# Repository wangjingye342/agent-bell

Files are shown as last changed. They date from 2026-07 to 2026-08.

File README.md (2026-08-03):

# AgentBell

独立的桌面小工具项目：电脑上 **Claude Code / Codex** 完成一轮对话时，局域网里的 ESP32-C3 设备
**蜂鸣 + 震动**，并在 OLED 上显示「哪台电脑 / 哪个智能体 / 哪个对话」完成了。
还带一个**带登录的网页控制台**，手机/电脑可随时开关蜂鸣/震动/勿扰。

> 本项目独立于气象站「仿真器」(aurora-weather-station)，自成一个文件夹与 git 仓库，互不影响。

```
   电脑（可多台）                          局域网                 AgentBell 设备
 ┌──────────────────┐   POST /notify   ┌──────────────────────────────────┐
 │ Claude  Stop hook │ ───────────────▶ │ ESP32-C3（HTTP 服务器 + mDNS）    │
 │ Codex   notify    │                  │  → 蜂鸣 + 震动 + OLED 显示        │
 │ tools/agent-bell/ │                  │  + 网页控制台 agent-bell.local    │
 └──────────────────┘                  └──────────────────────────────────┘
```

## 目录

| 路径 | 内容 |
|---|---|
| `agent_bell/` | **设备固件**（ESP32-C3 + SSD1306 OLED）+ Wokwi 预览。见 [agent_bell/README.md](agent_bell/README.md) |
| `agent_bell/WIRING.md` | **接线表**（先看这个） |
| `tools/agent-bell-bridge/` | **推荐：电脑侧桥接程序**（托盘常驻，免 hook 自动转发系统通知 + 自动发现设备 + 远程设置）。见 [tools/agent-bell-bridge/README.md](tools/agent-bell-bridge/README.md) |
| `tools/agent-bell/` | 电脑侧 hook 方案（Claude/Codex 适配器，备用）。见 [tools/agent-bell/README.md](tools/agent-bell/README.md) |
| `tools/ino-sim/` | 从气象站项目拷来的**屏幕模拟器**（备用，见下） |

## 快速开始

1. 接线：照 [agent_bell/WIRING.md](agent_bell/WIRING.md)（⚠ OLED / 触摸必须 3V3）。
2. 填 WiFi + 改网页登录密码：编辑 [agent_bell/agent_bell.ino](agent_bell/agent_bell.ino) 顶部配置区。
3. 编译烧录（在本项目根目录下）：
   ```sh
   arduino-cli compile --fqbn esp32:esp32:esp32c3:PartitionScheme=huge_app --output-dir agent_bell/build agent_bell
   arduino-cli upload -p COM5 --fqbn esp32:esp32:esp32c3 --input-dir agent_bell/build agent_bell
   ```
4. 打开 `http://agent-bell.local/` 登录 → 点「发一条测试通知」自测。
5. 接电脑（二选一）：
   - **推荐**：装桥接程序（免 hook，Claude/Codex 发系统通知即自动转发），见 [tools/agent-bell-bridge/README.md](tools/agent-bell-bridge/README.md)。
   - 备用：hook 方案（Claude 的 Stop hook / Codex 的 notify），见 [tools/agent-bell/README.md](tools/agent-bell/README.md)。

## 关于 ino-sim 模拟器

`tools/ino-sim/` 是从气象站项目搬来的屏幕模拟器（把 Arduino 屏幕输出渲染成 PNG，让 AI 能"看到"UI 效果）。

**注意**：它目前只支持 Adafruit_GFX / ST7735（RGB565 彩屏），**还不能渲染本项目的 SSD1306 单色 OLED（U8g2 驱动）**。
所以本项目的界面预览暂时走 **Wokwi**（SSD1306 是 Wokwi 原生器件，见 [agent_bell/README.md](agent_bell/README.md)）或真机。
若以后想让 ino-sim 也能预览这块 OLED，需要给它加一个 SSD1306/U8g2 单色后端——可作为后续任务。

## 状态

- ✅ 已完成：WiFi 通知（蜂鸣 + 震动 + 中文屏显）、网页控制台（登录 + 开关蜂鸣/震动/勿扰 + 测试，设置存 flash）、
  电脑侧通知器 + 两个适配器（已本地端到端测过）、两版固件编译通过。
- ⏳ 待真机验证：接线上电、WiFi 连接、控制台、真跑一轮对话自动触发。
- 🔒 以后：长按录音 → 语音识别 → 回填输入框 → 双击确认发送（触摸手势、麦克风引脚 7/20/21 已预留）。

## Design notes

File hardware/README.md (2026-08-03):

# AgentBell 单板 PCB — 前期设计资料

把 AgentBell 从"面包板+杜邦线"集成到**一块嘉立创可打样+贴片**的板子。

> **当前状态：可行性/需求确认阶段，还不是可直接生产的设计源。**
> 先阅读 [FEASIBILITY_REVIEW.md](FEASIBILITY_REVIEW.md)，并填写
> [MEASUREMENTS_NEEDED.md](MEASUREMENTS_NEEDED.md)。`SCHEMATIC.md` 和 `BOM.csv` 是前期草案，
> 在实物尺寸、电源方案和最终料号确认前不能直接用于下单。

> 这份是人可读的前期方案，不是可直接上传 JLC 的 Gerber/CPL。实际原理图、布线、ERC/DRC、
> Gerber、BOM 和 CPL 仍需在 EDA 工具中完成和复核。

新增资料：

- [SUPERMINI_CARRIER_SPEC.md](SUPERMINI_CARRIER_SPEC.md)：SuperMini 尺寸、引脚、供电和手焊封装；
- [PCBA_STRATEGY.md](PCBA_STRATEGY.md)：除 SuperMini 外全部由嘉立创贴装的生产策略。
- [EDA_AUTOMATION_PLAN.md](EDA_AUTOMATION_PLAN.md)：嘉立创 EDA API 自动绘制、检查和生产文件导出方案。
- [POWER_PATH.md](POWER_PATH.md)：USB 优先、边充边用、自动电池切换和关机充电架构。
- [COMPACT_DESIGN.md](COMPACT_DESIGN.md)：主板尺寸目标、双面叠放和小型器件选择约束。

## 方案总览

- **主控**：ESP32-C3 SuperMini 使用自定义 2×8 混合封装平放手焊；这是唯一手焊电子器件。天线端
  **悬出板边或在其下方/前方完整禁铜**。
- **屏**：0.96" SSD1306 OLED（单独一块），主板出 **4P 排线座**（3V3/GND/SDA/SCL）引到外壳正面。
- **全 SMD 由 JLC 贴**：小型无源蜂鸣器、薄型 EC05 编码器、独立小型确认键、SMD 振动马达，
  以及全部驱动/阻容/触摸/电源器件。
- **触摸**：不用触摸模块——在 PCB 顶层做一块**铜箔触摸片**接 TTP223（周围挖空地铜、盖阻焊、丝印画图标）。
- **供电基线**：主板 USB-C + BQ24074 power-path + 单节锂电池 + 电源开关。插 USB 时 USB 优先
  供系统并同时充电；拔 USB 自动切换电池；关机仍能充电。
- **手工焊/装配**：只手焊 SuperMini；OLED、电池和旋钮帽采用插接/压装，其余电子器件由 JLC 贴好。

## 供电架构

```
主板 USB-C ──► BQ24074 power-path ──► 电池
                    │
                    └─► VSYS ──► 电源开关/后级升压 ──► 5V_SYS
                                                     ├─► SuperMini 5V
                                                     └─► 外设 3.3V
```
- 主板 USB-C 负责日常供电和充电；SuperMini 自带 USB-C 只作烧录服务口。
- 插 USB 时系统负载优先，余量用于充电；拔 USB 自动由电池供电。
- 电源开关关闭后系统负载断电，但充电管理仍工作。
- SuperMini 的 3.3V 输出与载板 3.3V 不相连，避免两个稳压器并联。
- 使用 SuperMini USB 烧录前必须把主电源关闭，并通过 PCB 防倒灌器件进一步隔离。

## 引脚分配（沿用现固件，避开 strapping 2/8/9）

| GPIO | 功能 |
|---|---|
| 1  | 编码器 CLK (A) |
| 3  | 蜂鸣器（经 SS8550 低有效驱动）|
| 4  | 触摸（TTP223 输出）|
| 5  | OLED SDA |
| 6  | OLED SCL |
| 7  | 编码器 DT (B) |
| 10 | 振动马达（经 SS8050 高有效驱动）|
| 20 | 编码器按键 SW |
| 3V3/GND | 供电 |
| 空闲 | 0, 21（可留调试焊盘）|

## 平面布局（小型双面叠放）

```
主板正面：USB-C / 充电电源 / 小型编码器 / 按键 / 触摸 / 蜂鸣器 / 马达 / 接口
主板背面：ESP32-C3 SuperMini 手焊，元件面朝外

目标板框：优先尝试约 24×32mm；若热设计、USB、天线或机械件无法满足，则控制在 28×38mm 内。
```
- SuperMini 与正面 SMT 器件在平面上重叠，利用双面面积；天线区域例外，所有层完整 keepout。
- 编码器、按键、触摸片和 USB-C 放在外壳可操作边；蜂鸣器声孔和马达受力面保持无遮挡。

## 嘉立创下单要点

1. 在立创EDA 画原理图（按 `SCHEMATIC.md` 连接表）→ 导入元件（按 `BOM.csv` 的 LCSC 编号）→ PCB 布局布线 → DRC。
2. 下单：PCB + SMT 贴片；小型版包含 QFN、电源器件、薄型编码器、蜂鸣器和马达。是否适用
   Economic PCBA、双面装配或治具，以最终 BOM 在下单页面的实时提示为准。
3. **不贴、留给你手工**：仅 SuperMini；它在 BOM/CPL 中标为 DNP。OLED、电池使用工厂已贴好的
   SMD 防呆连接器和预制线束。
4. 收板后：检查电源 → 手焊 SuperMini → 插接屏幕/电池 → 烧录固件。

详见 [SCHEMATIC.md](SCHEMATIC.md)（逐块原理图+连接表）与 [BOM.csv](BOM.csv)（元件+LCSC 编号）。

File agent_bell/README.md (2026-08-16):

# AgentBell 设备固件

ESP32-C3 + OLED + 蜂鸣器 + 震动 + 旋转编码器做的桌面小工具：
**电脑上 Claude Code / Codex 完成一轮对话 → 它蜂鸣 + 震动 + OLED 显示「哪台电脑 / 哪个智能体 / 哪个对话」。**

> 这是独立于 `weather_station` 气象站的新子项目，两者互不影响。

```
   电脑（可多台）                          局域网                 AgentBell 设备
 ┌──────────────────┐   POST /notify   ┌──────────────────────────────────┐
 │ Claude  Stop hook │ ───────────────▶ │ ESP32-C3 (HTTP 服务器 + mDNS)     │
 │ Codex   notify    │  computer/agent/ │  → 蜂鸣 + 震动 + OLED 显示        │
 │ tools/agent-bell/ │  conversation/…  │  agent-bell.local                 │
 └──────────────────┘                  └──────────────────────────────────┘
```

## 文件

| 路径 | 作用 |
|---|---|
| `agent_bell.ino` | 设备固件（WiFi + HTTP 服务器 + U8g2 中文 OLED + 蜂鸣/震动/编码器菜单）|
| `WIRING.md` | **接线表**（先看这个）|
| `secrets.example.h` | WiFi 凭据模板（复制为 `secrets.h` 填入，已 gitignore）|
| `diagram.json` / `wokwi.toml` | Wokwi 界面预览（可选，用 SIM_DEMO 版固件）|
| `../tools/agent-bell-bridge/` | **推荐：电脑侧桥接程序**（托盘常驻，自动转发系统通知 + 远程设置）（[说明](../tools/agent-bell-bridge/README.md)）|
| `../tools/agent-bell/` | 电脑侧 hook 方案 + Claude/Codex 适配器（备用）（[说明](../tools/agent-bell/README.md)）|

## 硬件

见 [WIRING.md](WIRING.md)：OLED(GPIO5/6)、旋转编码器(GPIO1/7/20)、蜂鸣器(GPIO3)、震动(GPIO10)。
⚠ OLED 和编码器必须 3V3 供电（C3 不耐 5V）。

## 构建 & 烧录

```sh
# 装库（一次）
arduino-cli lib install U8g2
# 编译（huge_app 分区容纳中文字库）
arduino-cli compile --fqbn esp32:esp32:esp32c3:PartitionScheme=huge_app \
    --output-dir agent_bell/build agent_bell
# 烧录（换成你的串口，如 COM5）
arduino-cli upload -p COM5 --fqbn esp32:esp32:esp32c3 --input-dir agent_bell/build agent_bell
```
> 本机 arduino-cli 用绝对路径 `/c/Program\ Files/Arduino\ CLI/arduino-cli.exe`；PATH 坑见项目记忆。
> 已验证：正式版占 3MB 分区的 40%（1.27MB），内存宽松。

## 首次使用

1. 复制 `secrets.example.h` 为 `secrets.h`，填入你的 WiFi（`secrets.h` 已 gitignore，不会上传）。
2. 按上面命令编译、烧录。
3. 上电后设备连 WiFi，待机屏出现（IP 可在旋钮菜单「设备状态」里看）。
4. 自测链路：转一下旋钮进菜单，选「模拟通知」→ 应蜂鸣 + 震动 + 屏显。
   从电脑发也行：浏览器访问 `http://agent-bell.local/api/test`，或命令行
   `python ../tools/agent-bell/notify.py --demo`。
5. 接上智能体（二选一）：
   - **推荐**：装[桥接程序](../tools/agent-bell-bridge/README.md)（托盘常驻，Claude/Codex 一发系统通知就自动转发，免 hook）。
   - 备用：hook 方案见[电脑侧说明](../tools/agent-bell/README.md)（Claude 的 Stop hook、Codex 的 notify）。
     本仓库已内置项目级 `.claude/settings.json`，**在本项目里结束一轮对话即会触发**（设备在线时）。

## 待机屏（左右半屏模块）

待机时屏幕分**左右两个 64×64 半屏**，各自从同一个模块池里任选，共 8 种：

**宇航员**（星空 + 自转太空人）· **数字时钟** · **模拟表盘** · **竖排大钟** · **日历** · **信息面板**（未读/WiFi/IP/开机时长）· **雷达扫描** · **流星夜空**

改法三选一（同一份设置，存 flash 掉电不丢）：

- 设备旋钮菜单「**左屏样式 / 右屏样式**」——选择器背景就是实时渲染的待机屏，转一格换一种，所见即所得；
- 桥接程序**设置窗口**的设备设置区；
- `POST /api/settings` 的 `lsty` / `rsty` 字段（0–7，顺序同上）。

时钟类模块的时间来自 SNTP（`ntp.aliyun.com`，UTC+8），联网后自动同步；未同步时显示 `--:--` 或占位表姿。

## 设置怎么调

分两类：

- **编译期**（改完要重新编译烧录）：`agent_bell.ino` 顶部配置区——引脚（OLED/蜂鸣器/震动/编码器）、
  `MDNS_NAME`、`OLED_ADDR`、震动极性 `VIB_ACTIVE_HIGH`、编码器每档沿数 `ENC_RAW_PER_DETENT`、
  提示音音序表 `MELODIES` / 震动节奏 `ALERT_VIB`。WiFi 凭据在 `secrets.h`（见上）。
- **运行期**（改完即生效，存 flash 掉电不丢，无需重烧）：
  - **设备旋钮菜单**（转=选，短按=进/确认，长按=返回），按使用频率分组排序：
    勿扰（短按即切，行内显示开/关）→ 通知组（提示音·停留自动试听、通知音量、通知震动）→
    反馈组（反馈方式、反馈音量、反馈震动——「反馈」指转/按旋钮时的提示，与通知独立）→
    待机屏（左/右屏样式）→ 旋钮（方向·短按即翻转、灵敏度）→ 省电组（自动熄屏、自动关机）
    → 立即熄屏、立即关机（深睡 µA 级，**转动**旋钮开机；按键不在 C3 唤醒脚
    范围内）、WiFi 状态（短按立刻重连）、重新配网 → 模拟通知、设备状态；
  - **桥接程序设置窗口**（设备在线时出现设备设置区）；
  - **HTTP API**：`POST /api/settings`（字段见下）。

## 电源与省电（电池供电必读）

v2 板的电池路径是 `VBAT → SS34 → SuperMini 板载 LDO → 3.3V`，余量只有零点几伏。
WiFi 发射峰值电流（19.5dBm 约 350mA）会把 3.3V 轨拽到欠压阈值以下 → 芯片复位 →
重启又连 WiFi → 又复位，表现为**屏幕定格 + 蜂鸣器连续响**（每次开机的初始化响一下）。

固件侧的应对：**只有一档「省电但够用」，没有模式可选**（板上既没有 USB 检测脚也没有
电池 ADC，固件无法自知供电来源，所以一律按电池的约束跑）：

| 项 | 取值 | 为什么 |
|---|---|---|
| 发射功率 | 按 RSSI 自适应 11 / 13 / 15 / 17dBm | 弱信号时不吝啬——TCP 重传比多发几个 dBm 更费电，也更容易撞穿电脑侧超时 |
| WiFi 休眠 | 调制解调器休眠（随 DTIM 醒来收包）| 省下的 ~60mA 连续电流是续航的大头；代价约 +0.1s 延迟，对提醒设备无感 |
| 主频 | 80MHz | 实测 HTTP 处理只占 p50 19ms，降频不影响响应 |
| 通知音量 | 封顶 70% | **防掉电，不是省电**：蜂鸣 ~200mA + 马达 ~100mA 会和 WiFi 收包峰值叠在刚收到通知那一刻 |

> 早期有「自动/性能/省电」三档，其中「自动」会在掉过一次电后**永久**锁死省电模式
> （NVS 粘性标记只写不清，插 USB 也回不去）。既然电池小、目标就是省电，现在直接
> 合并成一档，那个 bug 也随之消失。

配套措施：开机用缓存的 BSSID + 信道直连（跳过全信道扫描，缩短高电流窗口）；
掉电复位后先显示「电池电压不足」并等 2.5s（连续掉电 6s）让电芯回压再连网；
`esp_reset_reason()` 的掉电次数在菜单「设备状态」和 `/api/info` 的 `brownouts` 里可查
（正常供电恒为 0）。

> 根治要靠硬件：5V 节点加 220~470µF 缓冲电容、把 SS34 换成理想二极管省掉 0.4V 压降，
> 或按 `hardware/POWER_PATH.md` 的原方案加升压。

## HTTP 端点

所有端点均无需登录（仅限局域网用，HTTP 明文传输，别把设备暴露到公网）：

| 端点 | 作用 |
|---|---|
| `GET /` | **网页设置控制台**：全部设置读写 + 试听/试震 + 待看通知（手机/电脑输设备 IP 即用）|
| `GET /api/notes` | **待看**通知 JSON 数组（不是历史存档：设备上按一下旋钮即整批清空）|
| `GET\|POST /notify` | 收通知（`computer/agent/conversation/message`，表单编码；给 hook / 桥接程序用）|
| `GET /healthz` | 探活 |
| `GET /api/info` | 设备身份 JSON（`app:"agent-bell"`、mac、ip、rssi、uptime_s、brownouts 掉电次数、lowpower 是否已转省电；桥接程序扫描网段时靠它确认）|
| `GET /api/settings` | 读全部运行时设置（JSON，含 `melodies`/`panes` 名称表）|
| `UDP 47317` | 局域网发现应答：收到 `AGENTBELL?` 就把 `/api/info` 的 JSON 回给发送方。一个广播包替掉 254 次 TCP 扫描——那种扫描的突发会把设备自己打趴（实测漏检率 5%→20%），而 UDP 走 lwIP 自己的任务，不经 WebServer 的串行路径 |
| `GET /api/state` | `{info, settings, notes}` 一次拿完——设备一次只服务一个 HTTP 请求，多台电脑连时把 3 次请求合成 1 次是最实在的省 |
| `POST /api/settings` | 改设置，字段全部可选、只改传了的：开关 `buzz/vib/dnd/encrev/nwake`（0\|1）、强度 `bvol/vvol/fbvol/fbvib`（0–100）、`tone`（提示音 0–6）、`fb`（反馈方式 0–3）、`encdet`（灵敏度 1–3）、`lsty/rsty`（半屏样式 0–7）、`aoff`（自动熄屏分钟 0/1/2/5/10/20/30）、`apwr`（自动关机分钟 0/10/20/30/60/120/240）；另有动作参数 `play=1` 试听 / `vibtest=1` 试震。应答同 GET |
| `GET\|POST /api/test` | 注入一条固定测试通知，完整走响铃+震动+屏显，验证链路 |

## 操作（编码器）

**转** = 移动/调整，**短按** = 进入/确认，**长按 ≈0.5s** = 返回/回待机。详见 [WIRING.md](WIRING.md)。
（触摸模块已移除：其"返回"功能与编码器长按完全重合，且 PCB 放不下；GPIO4 空出留给以后的麦克风。）

## 界面预览（可选，不用真机）

两条路都行：

- **ino-sim（推荐，快）**：`tools/ino-sim` 已支持 U8g2 单色屏，一条命令把各个界面
  （待机各模块组合 / 通知 / 勿扰…）逐屏截成 PNG（场景脚本见
  [tools/ino-sim/scenarios/agent_bell.scn](../tools/ino-sim/scenarios/agent_bell.scn)，可注入 `lsty`/`rsty` 预览任意半屏组合）：
  ```sh
  python tools/ino-sim/simulate.py agent_bell/agent_bell.ino \
      --scenario tools/ino-sim/scenarios/agent_bell.scn --out tools/ino-sim/out_ab
  ```
- **Wokwi（交互式）**：用 `diagram.json` + `wokwi.toml`（VSCode 里 F1 → Wokwi: Start Simulator），
  指向 **SIM_DEMO 版**固件（开机自注入示例通知、跳过联网）：
  ```sh
  arduino-cli compile --fqbn esp32:esp32:esp32c3:PartitionScheme=huge_app \
      --build-property "compiler.cpp.extra_flags=-DSIM_DEMO" \
      --output-dir agent_bell/build-sim agent_bell
  ```

## 状态 / 下一步

- ✅ 已完成：WiFi 通知（蜂鸣 + 震动 + 中文屏显）、旋钮丝滑菜单（全部设置存 flash）、
  待机屏左右半屏模块（8 种可选 + 实时预览选择器）、网页设置控制台 + `/api/*` 桥接接口、
  电脑侧桥接程序 + hook 方案两条链路（已本地端到端测过）、ino-sim U8g2 界面预览。
- ⏳ 待真机验证：接线上电、WiFi 连接、`/api/test` 三件套、真跑一轮对话自动触发。
- 🔒 以后：长按录音 → 发电脑 → 微信输入法语音识别 → 回填输入框 → 双击确认发送（GPIO4 已空出留给麦克风）。

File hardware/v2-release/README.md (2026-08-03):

# AgentBell v2 载板 — 交付包（2026-07-28）

本目录是本轮 EasyEDA 设计（Claude + easyeda-agent 全程自动化 + 人工确认）的**最终交付物**。
EasyEDA 工程：AgentBell / Board3（Schematic3 + PCB3）。

## 文件清单

| 文件 | 用途 |
|---|---|
| `AgentBell-Gerber.zip` | **制造文件**，直接上传嘉立创下单（2 层 / 1.6mm / 过孔盖油，其余默认） |
| `AgentBell-BOM.csv` / `.xlsx` | **物料表**（带立创 C 号；CSV 为 UTF-16 Tab 分隔，Excel 打开无碍） |
| `s0-design-spec.json` | 设计档案：决策记录 / 引脚表 / BOM / 器件官方手册审计结论（s0-final-8） |
| `golden-netlist.json` | 金标准网表（22 网络，原理图与 PCB 双向对账基准） |
| `worklog/` | 过程工作文件（求解器脚本、中间 dump、审查材料），可整目录删除 |

## 板子速览

- **48 × 24mm**，左上 R10 圆角，双面 2 层
- 编码器轴心 = 圆弧圆心 **(10, 14)**；SuperMini 贴背面，USB 朝下悬出 2.4mm，天线朝上入全层禁布窗
- 锂电充电：TP4054 @ **147mA**（R8=6.8k，换 2k≈500mA）+ SS34 电源自动切换 + B+/B− 焊线孔
- 定位柱：Ø3.0 孔 ×3，孔心 (4,3.5) / (44.5,3.5) / (44.5,20.5)，间距 40.5 / 17.0 / 43.9mm
- 焊线孔全部丝印标注；阻容值全部丝印标注

## 已知无害项（下单可忽略）

1. DRC 剩 1 处 VBAT 同网重叠（铜皮合并，零风险）
2. 背面器件**位号**文字未镜像（平台 API 限制）；**阻容值标注是实物正向的**，焊接以它为准
3. 板厂 DFM 的丝印压盘/锐角提示为顾问级，正常生产

## 首次上电顺序

1. 不接电池，USB 直插 SuperMini → 整机应正常
2. 断 USB 接电池 → 电池带机
3. 电池 + USB 同插 → CHG 灯亮=充电中，充满自灭

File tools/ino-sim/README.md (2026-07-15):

# ino-sim — Arduino ST77xx / TFT screen simulator

Render an Arduino `.ino` sketch's TFT screen output to **PNG images + an HTML
gallery on your Mac**, so you (and the AI) can see exactly what the UI code draws
without flashing hardware.

Built for the ESP32-C3 + ST7735s (128×160) workflow, but works for any sketch
that draws through **Adafruit_GFX / Adafruit_ST7735 / Adafruit_ST7789** or
**TFT_eSPI**.

## How it works (why it's pixel-faithful)

The sketch is compiled on the host against thin Arduino shims, but its drawing is
redirected into an in-memory framebuffer using the **real Adafruit_GFX rendering
code** (vendored in `third_party/`). Because GFX draws *everything* — text,
lines, circles, the manual pixel arcs — through the same `drawPixel` path the
hardware uses, and `GFXcanvas16` applies the exact rotation transform the panel
applies via MADCTL, the rendered image matches the physical screen.

Both libraries share one engine: `GFXcanvas_fb` (extends the real
`GFXcanvas16`). `Adafruit_ST7735/ST7789` is a thin subclass; `TFT_eSPI` is an
API facade forwarding to the same engine — so common primitives render
identically across both.

```
.ino ──▶ simulate.py ──▶ clang++  (sketch + shims + real Adafruit_GFX + runtime)
                              │
                          framebuffer  ──▶ out/<frame>.png  +  out/index.html
                              ▲
                       scenario.scn  (sensor / time / touch inputs)
```

## Requirements

- macOS/Linux with `clang++` (or `g++`) and **zlib** (preinstalled on macOS).
- `python3`.

No Arduino toolchain or internet needed at run time. The canonical Adafruit_GFX
source is vendored under `third_party/Adafruit_GFX/` (BSD-licensed) for offline,
reproducible builds.

## Usage

```sh
# Capture all three pages of the demo sketch (uses scenarios/default.scn):
python3 tools/ino-sim/simulate.py sketch_jun18a/sketch_jun18a.ino

# Custom scenario, output dir, and upscale factor:
python3 tools/ino-sim/simulate.py path/to/sketch.ino \
    --scenario tools/ino-sim/scenarios/default.scn \
    --out tools/ino-sim/out --scale 4
```

Options:

| flag | default | meaning |
|---|---|---|
| `--scenario FILE` | `scenarios/default.scn` | scenario script to run |
| `--backend auto\|adafruit\|tft_espi` | `auto` | force a backend (auto-detected from `#include`s) |
| `--scale N` | `4` | integer nearest-neighbor upscale for the PNGs |
| `--out DIR` | `<tool>/out` | output directory |
| `--keep` | off | keep the generated `build/sketch.cpp` for debugging |

Outputs land in `out/`:
- `out/<name>.png` — one image per `snap`, upscaled `--scale`×. **Read these to
  see the UI.**
- `out/index.html` — a dark-themed gallery of all frames; open in a browser.

## Scenario DSL

A scenario is a plain-text script, one command per line; `#` starts a comment.
It sets inputs, advances simulated time while calling `loop()`, and snapshots the
screen. This lets you reach **any** UI state.

```
title My UI preview        # heading shown in index.html

touchpin 1                 # which GPIO the tap/hold commands drive (demo: 1)
temp 26.5                  # DHT.readTemperature() returns this (°C)
hum 60                     # DHT.readHumidity() returns this (%)
time 14:30:00              # NTP/getLocalTime clock; or "2026-06-19 14:30:00"
pin 3 high                 # set any input pin level (high/low/1/0)
analog 2 512               # set an analogRead() value

run 500ms                  # run loop() for 500 ms of simulated time
tap                        # short press touchpin (advance a page, etc.)
hold 1500ms                # long press (e.g. demo toggles the backlight)
snap climate               # capture the screen as out/climate.png
rotation 1                 # (rarely needed) force a rotation
```

Durations accept `us`, `ms`, `s`, or a bare number (= milliseconds). Time
advances **only** inside `run`/`tap`/`hold`, so `millis()`-based debounce and
refresh logic behave exactly as on hardware.

## Supported API

**Arduino core**: `Serial` (→ stderr), `millis/micros/delay`, `pinMode/
digitalRead/digitalWrite/analogRead`, `random`, `String`, `F()`/PROGMEM, math
macros, `Print::printf`.

**Libraries shimmed**: `Adafruit_GFX`, `Adafruit_ST7735`, `Adafruit_ST7789`,
`TFT_eSPI` (common drawing + text subset), `DHT`, `WiFi`, `time.h`
(`configTime`/`getLocalTime`).

**Not yet supported**: TFT_eSPI sprites (`TFT_eSprite`), smooth/anti-aliased &
custom-loaded fonts, true SPI timing. Sketches using those will fail to compile
or fall back to the GLCD font. The classic GLCD 5×7 font is fully supported and
matches hardware.

## Layout

```
simulate.py            orchestrator (ino→cpp, prototype-gen, compile, run)
scenarios/             scenario scripts (default.scn captures the 3 demo pages)
examples/              sample sketches (e.g. tft_espi_demo)
src/arduino_shim/      Arduino.h, Print, String, pgmspace, WiFi, DHT, time
src/gfx_backend/       GFXcanvas_fb engine + Adafruit_ST7735/ST7789 + colors
src/tft_espi_backend/  TFT_eSPI.h facade
src/runtime/           framebuffer PNG export, scenario parser, main, html viewer
third_party/Adafruit_GFX/  vendored canonical GFX (BSD)
build/ out/            generated (gitignored)
```

## Adding a sketch

Just point `simulate.py` at it. The orchestrator prepends `#include <Arduino.h>`
and auto-generates function prototypes (mirroring the Arduino IDE), and picks the
backend from the sketch's includes. Write a scenario that drives it to the states
you want to preview, then read the PNGs.

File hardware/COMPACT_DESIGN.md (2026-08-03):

# AgentBell 小型化设计约束

更新日期：2026-07-18

## 设计目标

在保持以下全部功能的前提下尽量减小主板和整机体积：

- ESP32-C3 SuperMini；
- USB 优先、锂电边充边用、拔线自动切电池；
- 电源开关，关机仍可充电；
- OLED 外接；
- 触摸按键；
- 旋转输入及确认/返回按键；
- 无源蜂鸣器；
- 振动马达。

小型化优先级：

1. 不能牺牲电气安全、天线性能和可制造性；
2. 优先减小 PCB 长宽；
3. 再控制整机厚度；
4. 仍需保留可操作的 USB、旋钮/转轮、按键和触摸区域；
5. 不为了几平方毫米使用难以采购或无法返修的非标准器件。

## 尺寸基准和目标

SuperMini 本体约 `18.0 × 22.5 mm`，因此它决定了主板的最小核心面积。

当前目标分两档：

| 目标 | 板框建议 | 说明 |
|---|---|---|
| 激进目标 | 约 24 × 32 mm | 需要双面高密度布局、超小编码器/按键，接口位置受限 |
| 稳妥目标 | 不超过 28 × 38 mm | 仍然很小，电源热设计、USB、声孔和连接器更容易安排 |

最终板框以元件真实 courtyard、天线 keepout、USB 插头空间和外壳操作面为准。不会为了满足一个预设
数字而违反 DRC 或挤压散热铜皮。

电池和 OLED 不计入主板板框，但通常会决定整机最终长宽和厚度。

## 双面叠放策略

- 嘉立创贴装器件集中在主板正面；
- SuperMini 作为唯一手焊件放在主板背面，元件面朝外；
- 主板正面器件可以与 SuperMini 在 XY 方向重叠，以节省平面面积；
- SuperMini 对应区域避免顶层过孔残桩和高出焊点；
- 天线端的上下两面和所有铜层做完整 keepout，且不放电池和线缆；
- BQ24074 的散热焊盘、USB 输入电容和功率地回路优先于极限压缩；
- 升压芯片、电感和输入/输出电容紧凑成一组，不跨板走大电流回路；
- 蜂鸣器声孔、马达受力面和触摸电极不能被 SuperMini 或电池遮挡。

## 小型器件基线

| 功能 | 原候选 | 小型化候选 | 大致外形/封装 | 结论 |
|---|---|---|---|---|
| 充电和 power-path | TP4056 草案 | BQ24074RGTR / C54313 | QFN 3×3 mm | 锁定候选 |
| 5V 升压 | 未定 | TPS61023DRLR / C919459 | SOT-563 1.6×1.2 mm | 优先候选 |
| 编码器 | EC11J1525402 / C209762 | EC05E1220401 / C116648 | 约 7.6×6.2×2.7 mm | 待机械确认 |
| 编码器按键 | EC11 内置 | EVQ-P7K01P / C5736840 | 约 3.5×2.9 mm | EC05 无按压时使用 |
| 蜂鸣器 | MLT-8530 / C94599 | MLT-5020 / C94598 | 约 5.2×5.2×2.5 mm | 小体积优先 |
| 触摸 | 淘宝模块 | TTP223 小封装 + PCB 电极 | IC 小封装 | 锁定方向 |
| 电池连接器 | PH2.0 | 1.0/1.25mm 卧贴防呆座 | 2P/3P | 等电池线束确认 |
| OLED 连接器 | PH2.0 4P | 1.0mm 卧贴 4P | 4P | 等屏幕线束确认 |
| 阻容 | 0402 | 0402 | 1.0×0.5 mm | 保持，兼顾密度和返修 |

## 旋转输入的取舍

原来的 EC11 约 15 × 18 mm，且高度超过 20 mm，是主板小型化的最大障碍，正式小型版不再使用。

EC05 是 5mm 中空轴的薄型编码器，适合做侧边拨轮/小转盘，但预计不包含 EC11 那样的按压开关。
因此保留两个输入：

- EC05：旋转菜单；
- 独立小型贴片轻触键：确认/短按/长按返回。

固件可继续使用原 `ENC_SW` GPIO20，电气功能不变，只是物理按键从旋钮轴下移到旁边。

如果最终必须坚持“旋钮本身可按压”，主板需要改用更大的 EC11 类器件，PCB 长宽或厚度必然增加。

## 蜂鸣器和马达

MLT-5020 相比 MLT-8530 面积明显更小，但声压约 75dB，低于原候选的 80dB；正式板会保留 MOSFET
驱动和匹配其 4kHz 特性的音调设置。若真机感觉不够响，可升级到稍大的 MLT-5030（约 80dB），
无需改变整体架构。

振动马达的尺寸直接影响体感。8mm 马达搜索到的候选是引线/通孔类型，不符合“只有 SuperMini
手焊”的要求；因此优先寻找嘉立创可 SMT 的最小扁平马达。若最小可自动贴装马达需要治具，需在
下单成本和体积之间取舍。

## PCB 工艺约束

- 默认 4 层板有利于在小面积内保持连续地平面、电源完整性和天线隔离；若成本优先再评估 2 层；
- 0402 阻容；不主动使用 0201；
- 功率线、USB 输入、充电和马达回路不按普通信号线最小线宽处理；
- QFN 散热焊盘需要合理钢网开窗和接地过孔；
- USB-C 固定脚、编码器/按钮受力区不能因为缩板而削弱铜皮和板边距离；
- 板框确定后输出 1:1 PDF，与 SuperMini、USB 插头、电池和 OLED 实物叠放检查。

## 外壳和整机体积

主板做到很小后，电池往往成为最大器件。电池容量越大，整机厚度/面积越大。最终应选择扁平 LiPo
贴在主板远离天线的一侧，并通过绝缘片隔离。电池不得覆盖 ESP32 天线，也不得压在蜂鸣器声孔或
触摸电极背面。

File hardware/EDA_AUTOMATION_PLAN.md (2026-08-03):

# 嘉立创 EDA 自动绘制与生产文件方案

更新日期：2026-07-18

## 结论

本机具备直接生成嘉立创 EDA 专业版工程和生产文件的可行工具链。推荐使用嘉立创/EasyEDA 的
官方 API skill 与 API Gateway，而不是仅靠鼠标自动化绘制。

已确认环境：

- 嘉立创 EDA 专业版 `V3.2.166` 已安装并正在运行；
- 本机安装包含 `pro-api 0.3.4` 接口定义；
- 已安装 Codex skill：`C:\Users\wjy\.codex\skills\easyeda-api`；
- skill 提供原理图、PCB、封装、工程管理、DRC 和制造数据导出 API；
- 当前尚未检测到 EasyEDA Bridge 服务，EDA API Gateway 扩展仍需安装/启用。

## 推荐工作流

```text
确定电源与机械要求
    ↓
API 查询嘉立创器件库、锁定 LCSC 料号和真实封装
    ↓
创建嘉立创 EDA 原理图
    ↓
ERC / 电源与驱动复核
    ↓
创建 PCB、板框、SuperMini 自定义封装和天线 keepout
    ↓
器件布局、布线、铺铜
    ↓
DRC + 3D/机械检查 + BOM/库存检查
    ↓
导出生产包
```

## 可以生成的交付物

最终 `hardware/production/` 计划包含：

- 嘉立创 EDA 专业版工程备份文件（`.epro`/`.epro2`）；
- 原理图 PDF；
- Gerber ZIP；
- 钻孔文件（包含在 Gerber 包内并单独复核）；
- BOM（CSV/XLSX，含 LCSC 料号）；
- Pick and Place / CPL 坐标文件；
- PCB 3D STEP 文件；
- 装配图和关键极性说明；
- DRC/ERC 检查记录；
- `ORDER_README.md`，列明嘉立创下单选项、DNP 器件和后焊 SuperMini 方法。

Gerber 可用于多数 PCB 厂打裸板；Gerber + BOM + CPL 用于嘉立创 PCBA。嘉立创 EDA 原生工程便于
在下单前继续人工检查和修改。

## 仍然不能跳过的检查

“能自动生成”不等于“未经检查就安全下单”。最终下单前至少要确认：

1. 电池容量、是否自带保护板、连接器型号和极性；
2. 外壳/板框尺寸、安装孔和编码器位置；
3. SuperMini 实物与 1:1 自定义封装重合；
4. OLED 实际线序、连接器和线长；
5. 蜂鸣器声孔、马达治具和编码器高度；
6. 嘉立创下单页面上的库存、贴装方向、扩展料和治具费用；
7. ERC/DRC 无未解释错误；
8. Gerber、BOM、CPL 在下单预览器中再次核对。

## 锂电版本的电源原则

用户已经确认需要 USB 优先、边充边用和自动电池切换。正式架构见
[POWER_PATH.md](POWER_PATH.md)，主充电/电源路径芯片暂定 `BQ24074RGTR / C54313`。

正式方案会加入：

- 单节锂电池连接器；
- 充电管理；
- 电池保护（若电池本身不带保护）；
- 电源开关；
- 明确的 USB/电池电源路径；
- 3.3V 稳压和负载瞬态储能；
- 电池电压检测（建议）；
- 防反接/过流保护和测试点。

不再使用旧草案的 `TP4056 + LDO`。BQ24074 负责充电和 power-path；电源开关控制后级系统电源，
关机时仍能充电。SuperMini 的烧录 USB 与主板日常充电 USB 分开，并增加防倒灌和丝印警告。

## 工具接入前置步骤

1. 在嘉立创 EDA 专业版安装并启用 `run-api-gateway.eext`；
2. 启动本机 EasyEDA Bridge 服务；
3. 验证 Bridge 健康状态和唯一 EDA 窗口连接；
4. 先执行只读 API：读取当前工程、文档和器件库；
5. 新建独立工程 `AgentBell-PCB`，不覆盖当前空白/测试工程；
6. 分阶段保存快照，原理图确认后再开始 PCB。

EDA 扩展安装完成后，可以从 API 自动建工程开始推进。

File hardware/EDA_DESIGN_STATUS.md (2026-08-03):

# AgentBell 嘉立创 EDA 设计状态

更新时间：2026-07-18

## 当前工程

- 工程：`AgentBell`
- Board：`Board1`
- 原理图：`Schematic1 / P1`
- PCB：`PCB1`
- PCB 文档 UUID：`043746d370790ae8`
- Bridge：已连接，后台 API 操作正常

`pcb_Document.importChanges()` 在当前嘉立创 EDA/Bridge 版本中会后台执行，未必显示“应用变更”窗口。因此，是否同步成功必须通过器件、UniqueId 和焊盘网络审计判断，不能以是否弹窗为准。

## 已完成

- 保留并整理了 55 个功能器件。
- 补入并关联了 `U1 BQ24074RGTR`，原理图/PCB UniqueId 为 `gge1`。
- 重建原理图的网络端口和短导线，消除了相邻引脚坐标重叠造成的意外短接。
- 修正了充电、升压、LDO、I2C 上拉和状态灯等错误网络。
- 逐器件比较原理图与 PCB：位号、UniqueId、全部焊盘网络为 0 处差异。
- PCB 已完成首轮紧凑布局。
- 当前板框约 `36.0 mm x 46.0 mm`。
- PCB 已切换为 4 层：Top / Inner1 / Inner2 / Bottom。
- ESP32-C3 SuperMini 放在 Bottom 层，其余主要 SMT 器件放在 Top 层。
- 当前工程已保存，并在 `hardware/backup` 中保存了多个可回退版本。

## 尚未完成

- PCB 铜线尚未完成。
- GND 平面、接地过孔、SuperMini 天线完整禁布区尚未最终建立。
- 当前 DRC 仍会报告未布线连接错误。
- 仍有少量器件间距和封装内部槽孔检查项需要处理。
- 尚未生成可用于下单的 Gerber、BOM、CPL 和装配图。

## 自动布线接口情况

当前环境的 `pcb_Document.autoRouting()` 会在 0 ms 内返回全部网络失败，即使：

- 原理图与 PCB 逐焊盘网络一致；
- U1 的 UniqueId 已修复；
- PCB 已切换为 4 层；
- 飞线计算能够正常启动。

因此不能依赖该接口完成布线。后续应采用 API 手工分网布线，或在嘉立创 EDA 中使用前端布线功能。

## 投板限制

当前版本绝对不能直接投板。至少还需要：

1. 完成全部铜线和 GND 平面；
2. 建立 ESP32-C3 天线区域上下层禁铜、禁过孔、禁器件；
3. 复核 BQ24074 与 TPS61023 的高电流回路和散热；
4. DRC 中未布线错误归零，并处理真实间距错误；
5. 确认电池容量、允许充电电流、保护板、连接器极性；
6. 导出并复核 Gerber、BOM、CPL 和装配图。

## 当前关键风险

- 电池规格仍未确认，现有 `R1=1.78k` 对应的充电电流不应在未知电池上直接使用。
- SuperMini 自带 USB 与主板 5V 供电之间必须遵守防倒灌/烧录时断主电源要求。
- 贴片马达、蜂鸣器、编码器和连接器仍需结合实际外壳确认机械方向。

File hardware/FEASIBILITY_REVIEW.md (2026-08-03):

# AgentBell 集成 PCB 可行性评审（2026-07-18）

## 结论

这些功能可以集成到同一块主 PCB：

- ESP32-C3 SuperMini 主控子板
- 无源蜂鸣器及驱动
- 振动马达及驱动、续流保护
- 电容触摸按键
- 带按压的旋转编码器
- OLED 屏幕外接接口
- 电源输入、滤波、测试点和调试接口

屏幕继续做独立板很合理。第一版建议把主板定位为 **SuperMini 载板**，而不是立即把
ESP32-C3 芯片、Flash、晶振、USB 电路全部重画一遍。这样既能沿用现有固件，又能显著降低 RF、
USB 下载和焊接风险。

用户已确认装配目标：**除 ESP32-C3 SuperMini 手焊外，其余主板器件尽量全部由嘉立创贴装。**
现有候选蜂鸣器、编码器和振动马达均有嘉立创 SMT 条目；其中振动马达需要装配治具。详细安排见
[PCBA_STRATEGY.md](PCBA_STRATEGY.md)。

目前目录内的 `SCHEMATIC.md`、`BOM.csv` 是前期方案，不应直接用于下单。打板前还需要完成：

1. 确认所有实物的机械尺寸和引脚顺序；
2. 决定 USB 常供电还是锂电供电；
3. 确认 SuperMini 能否平贴焊接；
4. 用最终选定的立创商城料号核对封装、库存和贴装属性；
5. 画出真实 EDA 原理图/PCB，完成 ERC、DRC、Gerber 和坐标文件检查。

当前暂定首版为 USB 常供电，以便先完成明确且低风险的载板设计。如果用户确认必须加入锂电，正式
原理图将切换到带充电、保护和电源路径的版本。

## 从代码确认的接口

固件 `agent_bell/agent_bell.ino` 当前使用：

| 功能 | GPIO | 电气方向/说明 |
|---|---:|---|
| 编码器 A | 1 | 输入，上拉，双边沿中断 |
| 蜂鸣器 | 3 | PWM/音调输出；当前固件按“低有效 PNP 驱动”编写 |
| 触摸 | 4 | 数字输入；固件会在启动时学习空闲电平 |
| OLED SDA | 5 | I2C，3.3V |
| OLED SCL | 6 | I2C，3.3V |
| 编码器 B | 7 | 输入，上拉，双边沿中断 |
| 振动马达 | 10 | 20kHz PWM，高有效 |
| 编码器按键 | 20 | 输入，上拉，按下接地 |

代码避开了 GPIO2、GPIO8、GPIO9，并保留 GPIO0、GPIO21。PCB 上应把 0、21、3V3、GND、EN
做成测试焊盘，便于首板调试。

## 推荐的首版架构

### 方案 A：USB 常供电载板（推荐首板）

使用 SuperMini 自带 USB-C 负责供电和烧录：

```text
SuperMini USB-C
  ├─ 板载稳压器：只负责 SuperMini 自身 3.3V
  └─ 5V/VBUS 焊盘 → 载板 3.3V 稳压器 → OLED/触摸/编码器/蜂鸣器/马达
                                      └→ 蜂鸣器、马达各自经过驱动
```

优点：电路少、没有双 USB 口、没有充电和电源路径问题，最适合验证布局、交互和驱动电路。

新增资料已经确认 SuperMini 引出了 5V/VBUS、GND 和 3.3V。载板默认从 5V/VBUS 取 USB 电源并
自行稳压，不把两个 3.3V 稳压器输出并联。开发板资料明确要求外部供电和 USB 不能同时使用；详见
[SUPERMINI_CARRIER_SPEC.md](SUPERMINI_CARRIER_SPEC.md)。

### 方案 B：锂电版（第二版或确认需求后再做）

锂电版需要同时考虑电芯保护、充电电流、边充边用的电源路径和低电压关断。当前草案的
“TP4056 + LDO 直接带载”可以工作于某些场景，但不适合在参数未确认时直接出板：

- TP4056 本身不是完整的负载共享/电源路径管理；
- 1.2kΩ PROG 约对应 1A 充电，未必适合小电池；
- 电池电压下降后，普通 3.3V LDO 会逐渐失去稳压余量；
- 电池保护取决于电芯是否自带保护板；
- SuperMini 自带 USB 和主板充电 USB 同时插入时必须避免电源互相顶住。

如果确实需要电池，建议单独确定续航、充电口数量、电池容量和是否要求边充边用，再选择带
power-path 的充电方案或做明确的电源隔离。

## 各模块怎样集成

### 1. ESP32-C3 SuperMini

新增资料确认该版本约 18.00 × 22.50 mm、2×8 焊盘、两排基准间距 15.24 mm。首版做
**混合兼容手焊封装**：通孔用于定位/加固，外侧加长焊盘用于模块平放后的烙铁接触。模块覆盖区不
放元件，天线端伸出主板或做完整禁铜区。正式投板前仍需用 1:1 封装打印图与手头实物叠放核对。

### 2. 无源蜂鸣器

用户提供的 PDF 显示模块由无源蜂鸣器、9012 类 PNP 三极管和基极电阻组成，是低有效高边驱动。
PDF 上电阻标注为 22Ω；不建议未经实测就原样复制，尤其不应把该模块直接以 5V 供电并由 3.3V
GPIO 驱动。

推荐主 PCB 使用裸无源蜂鸣器 + 独立驱动：

- 首选逻辑电平 N-MOSFET 低边驱动，蜂鸣器电源可通过焊接跳线选择 3.3V/5V；
- GPIO 只驱动 MOSFET 栅极，不承担蜂鸣器电流；
- 采用低边驱动后，需要把固件蜂鸣器极性改为高有效；
- 若坚持完全不改固件，可保留 3.3V PNP 高边方案，但不要提供未经电平转换的 5V 档。

如果要拆现有模块上的蜂鸣器复用，必须测量蜂鸣器本体尺寸、脚距，并确认它确实是无源型号。

### 3. 振动马达

马达不能直接接 GPIO。推荐使用逻辑电平 N-MOSFET 低边驱动，并在马达两端放续流二极管。马达
附近增加 0.1µF 抑制电容，负载电源入口增加储能电容，电机大电流回路不要穿过 ESP32/OLED 的
地回路。

淘宝模块整板通常不能作为标准 SMT 料自动贴装。可选择：

- 主 PCB 做马达驱动，保留 2P 焊盘/连接器，复用现有马达；
- 选立创可贴的 SMD 币式马达，但必须用其官方封装并确认装配限制；
- 首板由你手工焊马达，风险最低。

### 4. 触摸开关

最适合集成：不再安装淘宝触摸模块，而是把 TTP223 类触摸 IC、去耦电容和触摸铜箔直接画在
主 PCB 上。触摸电极周围及其正下方要按触摸设计留出净空，并预留灵敏度电容焊盘。

如果触摸区域隔着较厚外壳，需先确定外壳材料和厚度；这会直接影响铜箔面积和灵敏度。

### 5. 旋转编码器

小型版不再使用 HW-040/大 EC11。当前优先候选为 `EC05E1220401 / C116648`，约
7.6×6.2×2.7mm，由嘉立创贴装。它使用中空轴转轮，若不带按压，则增加
`EVQ-P7K01P / C5736840` 小型贴片按键接原 GPIO20，固件功能保持不变。机械结构仍需在外壳阶段
确认拨轮直径、手指接触空间和按键位置。

### 6. OLED

屏幕分板保留。主板提供 4P 防呆连接器，并把引脚顺序同时印在丝印上：`3V3/GND/SDA/SCL`。
连接器型号和屏幕端线序必须最终确认；不能只写“JST 4P”，因为 PH、SH、XH 的间距完全不同。

## 嘉立创下单时哪些可以直接贴

“可以直接有”并不只取决于它是不是 SMD，还取决于下单当日的库存、封装、贴装面、器件高度和
装配规则。因此最终以立创 EDA/JLCPCB 下单页的 BOM 匹配结果为准。

| 类别 | 建议 | 原因 |
|---|---|---|
| 0402/0603/0805 阻容、LED | 工厂贴 | 标准 SMT，最适合自动贴装 |
| MOSFET/三极管、二极管、TTP223、电源 IC | 工厂贴 | 有明确 LCSC 料号和封装即可 |
| USB-C、常见 SMD JST 座、滑动开关 | 可工厂贴 | 需锁定精确料号、开口方向和机械孔 |
| SMD 蜂鸣器 | 工厂贴 | 小型版候选 C94598，约5.2mm，必须配独立驱动 |
| SMD 薄型编码器 | 工厂贴 | 小型版候选 C116648；独立确认键 C5736840 |
| 币式振动马达 | 工厂贴 | C22359894 当前候选支持 SMT，但需要装配治具 |
| ESP32-C3 SuperMini 整板 | 手焊 | 淘宝开发板不是标准 LCSC SMT 物料；平贴还依赖实物边缘焊盘 |
| 淘宝触摸/蜂鸣器/马达/HW-040 模块整板 | 手焊或取消模块 | 模块通常没有标准 PCBA 贴装料号和机器可识别包装 |
| OLED 模块、旋钮帽、锂电池、外接线 | 后装/手工装配 | 属外部模块或机械装配件 |

用户自己提供的散件并不等于经济型 PCBA 会自动帮忙贴。若要让工厂使用客供料，通常需要走
客供料/特殊装配流程并增加沟通和成本；对 5～10 块首板，自己焊关键机械件更合适。

## 打板前必须补齐的实物信息

请按 `MEASUREMENTS_NEEDED.md` 测量或拍照。尤其需要：

1. SuperMini 正反面高清照片，旁边放尺子；
2. SuperMini 两排孔的中心距、纵向脚距、板厚、底面最高元件高度；
3. 蜂鸣器模块正反面和丝印，蜂鸣器本体直径/高度/脚距；
4. 马达模块正反面、马达额定电压和启动/运行电流；
5. 触摸模块芯片丝印、输出空闲电平；
6. 编码器模块和裸编码器的轴高、轴型、安装孔尺寸；
7. OLED 接口间距、实际线序和连接方式；
8. 供电选择：长期 USB，还是必须电池；若用电池，提供容量和是否带保护板。

淘宝商品页在本次检查时跳转到了登录页，无法可靠读取 SKU 和尺寸，所以不能拿商品标题或其他
卖家的相似图片代替实物测量。

## 首版 PCB 的建议边界

首版目标应是“电气可靠、接口正确、能装进预期外壳”，而不是一次把所有特殊器件都交给工厂贴：

- JLC 贴：阻容、MOSFET、二极管、触摸 IC、连接器、蜂鸣器、编码器、振动马达；
- 你手焊：仅 SuperMini；OLED、电池等使用插接线束后装；
- PCB 同时给蜂鸣器和马达留替代封装/2P 接口，避免某一个淘宝器件尺寸不合导致整板报废；
- 所有外接接口旁标注电压、信号名和 1 脚；
- 预留 0Ω/焊接跳线用于选择蜂鸣器/马达电源和调整触发极性。

完成首板验证后，再把已确认的蜂鸣器、马达、编码器改成 JLC 全贴版本，成功率会高很多。

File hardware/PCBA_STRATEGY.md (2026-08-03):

# 嘉立创 PCBA 装配策略

目标：嘉立创完成主板上除 ESP32-C3 SuperMini 外的全部器件贴装；收到板后，只手焊 SuperMini，
再插接 OLED 和外部电池/线缆（若采用）。

## 工厂贴装

| 功能 | 当前候选 | 贴装结论 | 设计注意 |
|---|---|---|---|
| 无源蜂鸣器 | MLT-5020 / C94598 | SMT | 约5.2mm、75dB、4kHz，必须配驱动 |
| 旋转编码器 | EC05E1220401 / C116648 | SMT | 约7.6×6.2×2.7mm，中空轴，需确认拨轮结构 |
| 确认/返回键 | EVQ-P7K01P / C5736840 | SMT | 独立替代原EC11内置按压，接GPIO20 |
| 振动马达 | LCM1027A3670F / C22359894 | SMT | 3V/80mA；嘉立创注明需要装配治具 |
| 触摸 | TTP223 + PCB 铜箔 | SMT/PCB 本体 | IC、电容工厂贴；触摸电极直接做在 PCB 上 |
| 驱动 | MOSFET、二极管、阻容 | SMT | 蜂鸣器、马达都不直接由 GPIO 带负载 |
| OLED 接口 | 待定 4P SMD 防呆座 | SMT | 必须同时确定线端插壳和端子，不只选板端座 |
| 电源器件 | 稳压器、滤波、开关等 | SMT | 最终随 USB 常供/锂电方案确定 |

这些候选在建立最终 BOM 时还要再次检查：库存、贴装面、旋转角度、封装版本和装配附加费用。

## 用户后焊/后装

| 项目 | 方式 |
|---|---|
| ESP32-C3 SuperMini | 平贴/短排针手焊到自定义 2×8 兼容封装 |
| OLED 屏幕板 | 使用预制线束插接，不焊主板 |
| 电池（若使用） | 插接到已由工厂贴好的板端座 |
| 旋钮帽 | 压入编码器轴 |

## PCB 工艺安排

- 尽量将所有自动贴装器件放在同一面，减少双面贴装成本和流程复杂度；
- SuperMini 放在另一面或留在同面独立空区，BOM/CPL 标 DNP；
- 马达、蜂鸣器、编码器均属于机械/声学器件，不能只看原理图，还要在 3D/装配图检查高度、开孔和
  受力；
- 蜂鸣器声孔上方不得被外壳或 SuperMini 遮挡；
- 振动马达附近应有足够板面支撑，避免放在窄悬臂或 PCB 开槽旁；
- 编码器按压会向 PCB 施力，附近布置安装孔或外壳支撑柱；
- PCBA 下单时查看马达治具提示和报价，若小批量治具费用不合理，再更换无需治具的封装/料号，而
  不是临时改为手焊。

## 验收顺序

1. 收到已贴装主板后，先不焊 SuperMini，检查 5V/3.3V 对地是否短路；
2. 用限流电源给主板供电，检查稳压轨；
3. 手焊 SuperMini；
4. 首次上电限制电流，先验证 OLED/I2C 和输入器件；
5. 再分别测试蜂鸣器、马达，最后测试同时工作和 Wi-Fi 发射时的电源稳定性。

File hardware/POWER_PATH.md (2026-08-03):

# AgentBell 锂电、USB 优先和边充边用电源架构

更新日期：2026-07-18

## 已确认的使用行为

1. 未插 USB：单节锂电池给整机供电；
2. 插入主板 USB-C：USB 优先给整机供电；
3. 电池未满：USB 同时给系统供电并给电池充电；
4. 电池充满：充电自动终止，系统继续由 USB 供电；
5. USB 供电能力不足或负载出现短时峰值：充电电流先降低，必要时电池辅助系统；
6. 拔掉 USB：自动转为电池供电，不需要用户切换电源来源；
7. 电源开关 OFF：关闭整机负载，但 USB 插着时仍允许电池充电。

这需要真正的 power-path/load-sharing 充电管理器，不能用 TP4056 的 BAT 节点直接并联系统负载。

## 暂定主芯片

| 功能 | 型号 | LCSC | 封装 | 状态 |
|---|---|---|---|---|
| 单节锂电充电 + 动态电源路径 | BQ24074RGTR | C54313 | QFN-16-EP 3×3 mm | 正式候选 |

选择原因：

- 嘉立创器件库已有符号、封装和 3D 模型；
- 支持单节 4.2V 锂电；
- OUT 系统节点可由 USB 输入或电池自动供电；
- 系统负载优先，输入能力不足时自动降低充电电流；
- 支持电池补充系统峰值电流；
- 输入限流、快充电流和终止电流均可通过外部电阻配置；
- 提供 CHG、PGOOD 状态和电池 NTC 温度检测。

最终投板前必须按 TI 最新数据手册逐脚复核，而不是只依赖库符号。

## 系统框图

```text
主板 USB-C 5V
      │
      ├─ CC1/CC2 5.1k 下拉、ESD/保险保护
      │
      ▼
 BQ24074 IN
      │
      ├────────────► BAT ──► 单节锂电池
      │                    （自带保护板，或主板增加保护电路）
      │
      ▼
 BQ24074 OUT / VSYS
      │
      ├─ 充电和状态灯始终工作
      │
      └─ 电源开关 ──► 后级升压 EN
                         │
                         ▼
                    5V_SYS 稳压轨
                      ├─► 隔离/防倒灌 ──► SuperMini 5V 脚
                      └─► 3.3V 稳压 ──► OLED/触摸/编码器/蜂鸣器/马达
```

## 为什么后级需要升压

BQ24074 的系统输出在插 USB 时约为固定系统电压，拔掉 USB 后会接近电池电压。电池从满电到低电
期间不足以始终作为稳定的“5V”。ESP32-C3 SuperMini 又保留了自己的板载 3.3V 稳压器，所以首版
不直接并联主板 3.3V 与 SuperMini 3.3V，而是：

1. 把 VSYS 升压为稳定 `5V_SYS`；
2. 通过防倒灌器件送入 SuperMini 的 5V 焊盘；
3. SuperMini 使用自身稳压器供给自己的 ESP32-C3；
4. 主板另从 `5V_SYS` 生成外设 3.3V。

升压器需要：

- 输入覆盖单节锂电工作范围；
- 5V 输出能力满足 Wi-Fi、蜂鸣器和马达同时动作；
- 有 EN 引脚，供机械电源开关控制；
- 关闭时低静态电流；
- 输出侧尽量具有真关断或增加独立负载开关/反向电流阻断。

具体升压芯片和 LCSC 料号将在估算整机峰值电流后锁定。

## 两个 USB-C 的使用规则

主板会有两个物理 USB-C：

| 接口 | 用途 |
|---|---|
| 主板 USB-C | 日常供电、给电池充电、边充边用 |
| SuperMini 自带 USB-C | 固件烧录/调试服务口 |

SuperMini 原理图显示其 5V 焊盘与自身 USB-C VBUS 直接相连。电池模式下由主板给该 5V 焊盘供电
时，其 USB-C VBUS 也可能出现电压。因此：

- 日常使用只插主板 USB-C；
- 使用 SuperMini USB-C 烧录前，必须把主电源开关拨到 OFF；
- 主板给 SuperMini 的 5V 支路加入反向电流阻断，防止烧录 USB 反灌回系统电源；
- PCB 丝印在 SuperMini USB 旁标注 `PROGRAM: POWER OFF FIRST`；
- 外壳设计可把 SuperMini USB 作为隐藏服务口，降低误插概率。

## 电源开关逻辑

开关不串在电池和充电芯片之间，而是控制后级系统电源：

```text
OFF：升压器/系统负载关闭；BQ24074 仍可给电池充电
ON ：升压器开启；系统由 BQ24074 OUT 供电，USB/电池来源自动选择
```

这种方式避免大电流全部流过小型机械开关，也允许关机充电。

## 电池保护和温度

- 如果使用带保护板的成品 LiPo，主板仍保留保险/反接防护和电池 NTC 接口；
- 如果电池不带保护板，主板必须加入单节电池过充、过放、过流和短路保护；
- 优先使用带 10k NTC 的 3 线电池；若最终电池只有 2 线，TS 网络必须严格按 BQ24074 数据手册
  设置，不能悬空猜接；
- 电池连接器必须明确 1 脚和极性，不能假设不同厂家的 JST 线序一致。

## 尚待电池参数决定的数值

以下参数不能在不知道电池规格时定版：

- 快充电流 `ICHG` / ISET 电阻；
- 充电终止电流 / ITERM 电阻；
- USB 输入电流上限 / ILIM 电阻；
- 是否装主板电池保护；
- NTC 网络；
- 电池电压检测分压和固件低电量阈值。

需要提供：电池标称容量、最大充电电流、是否带保护板、2 线/3 线、接头型号和实物极性照片。

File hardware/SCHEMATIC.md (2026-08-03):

# AgentBell 单板 原理图草案（连接表）

> **未定版、不可直接投板。** 本文件仍保留旧 TP4056 锂电方案作为历史草案。当前正式基线是主板
> USB-C + BQ24074 power-path + 后级系统电源、SuperMini 平贴手焊、其余器件由嘉立创贴装；应按
> [SUPERMINI_CARRIER_SPEC.md](SUPERMINI_CARRIER_SPEC.md) 和 [PCBA_STRATEGY.md](PCBA_STRATEGY.md)
> 以及 [POWER_PATH.md](POWER_PATH.md) 重画正式原理图，不要逐项照抄本文件。

电源网络：`VBUS`(USB-C 5V，仅充电) · `VBAT`(锂电正) · `3V3`(主电源轨) · `GND`。
按下面逐块在立创EDA连线即可。元件编号见 [BOM.csv](BOM.csv)。

---

## 1. 充电（TP4056，SOP-8）

| TP4056 脚 | 接到 |
|---|---|
| VCC(4) | VBUS；对地 10µF |
| BAT(5) | VBAT（→ 锂电 JST +）；对地 10µF |
| PROG(2) | R_prog 1.2kΩ → GND（设定 ~1A 充电）|
| CE(8) | VCC |
| CHRG(7) | → LED红 → R 1kΩ → VBUS（充电中亮，开漏拉低）|
| STDBY(6) | → LED绿 → R 1kΩ → VBUS（充满亮）|
| GND(3)+散热盘 | GND |

USB-C(16P) 座：VBUS/GND 取电；CC1/CC2 各 5.1kΩ 下拉到 GND（识别为受电端）；D+/D− 可不接。

## 2. 电源开关 + 3.3V LDO

| 网络 | 连接 |
|---|---|
| VBAT → 开关 | SPDT 滑动开关（SK-12D07）：公共=VBAT，一档→LDO_IN（ON），另一档悬空（OFF）|
| LDO(AP2112K-3.3, SOT-23-5) | IN=LDO_IN；EN=LDO_IN；GND=GND；OUT=3V3 |
| 电容 | IN 对地 1µF；OUT 对地 1µF + 22µF；3V3 轨再加 **100µF** 体电容（WiFi 峰值）|

> 3V3 同时供：SuperMini 的 3V3 脚、蜂鸣/马达/触摸/编码器、OLED。编程时开关拨 OFF。

## 3. 主控 ESP32-C3 SuperMini（2×8 母座，THT 手工）

| SuperMini 脚 | 接到 |
|---|---|
| 3V3 | 3V3 |
| GND | GND |
| GPIO1 | ENC_A（编码器 CLK）|
| GPIO7 | ENC_B（编码器 DT）|
| GPIO20 | ENC_SW（编码器按键）|
| GPIO3 | BUZ_DRV（→蜂鸣驱动）|
| GPIO10 | VIB_DRV（→马达驱动）|
| GPIO4 | TOUCH_OUT（←TTP223）|
| GPIO5 | I2C_SDA（→OLED 座）|
| GPIO6 | I2C_SCL（→OLED 座）|
| 其余脚 | 不接（可把 GPIO0/21 引到测试焊盘）|

天线端短边悬出板边，正下方 keepout（无铜、无地）。

## 4. 蜂鸣器（历史草案：MLT-8530 + SS8550）

> 小型正式版将改为 MLT-5020 / C94598 及重新核算的驱动电路，本节只保留旧方案参考。

```
3V3 ──emitter[SS8550]collector── Buzzer(+) ── Buzzer(−) ── GND
GPIO3 ──R 1kΩ── base ;  base ──R 10kΩ── 3V3(上拉，开机默认关)
```
GPIO3 输出低电平方波 → PNP 导通 → 蜂鸣器发声（固件 ToneBuzzer 就是低有效）。

## 5. 振动马达（SMD 币式 + SS8050 NPN，高电平触发＝配现固件）

```
3V3 ── Motor(+) ── Motor(−)=节点M ──collector[SS8050]emitter── GND
GPIO10 ──R 1kΩ── base
续流二极管 1N4148W：anode=节点M，cathode=3V3   ← 感性负载必须加，防反峰烧管/MCU
```
GPIO10 高 → NPN 导通 → 马达转（固件 VIB_ACTIVE_HIGH=true）。

## 6. 触摸（TTP223-BA6，SOT-23-6）

| TTP223 脚 | 接到 |
|---|---|
| VDD(5) | 3V3；VDD-VSS 就近 0.1µF |
| VSS(2) | GND |
| I(3) | **PCB 顶层铜箔触摸片**；可留 Cs 焊盘（I→GND，默认不贴=最灵敏）|
| Q(1) | GPIO4 |
| AHLB(4) | 悬空（默认高有效）|
| TOG(6) | 悬空（默认点动：按住输出有效）|

触摸片：顶层 8–15mm 铜箔，盖阻焊，正下方及四周挖空地铜；表面可覆薄亚克力。

## 7. 旋转编码器（历史草案：EC11）

> 小型正式版改用 EC05E1220401 / C116648，并增加独立小型确认键；本节不可直接照抄。

| EC11 脚 | 接到 |
|---|---|
| A | ENC_A(GPIO1)；上拉 10kΩ→3V3；去抖 10nF→GND |
| C（公共）| GND |
| B | ENC_B(GPIO7)；上拉 10kΩ→3V3；去抖 10nF→GND |
| SW1 | ENC_SW(GPIO20)；上拉 10kΩ→3V3；0.1µF→GND |
| SW2 | GND |

（固件已开 INPUT_PULLUP + 中断解码，外部上拉/电容是额外抗抖，更稳。）

## 8. OLED 排线座（4P，JST-PH2.0 或 1×4 排针）

| 座脚 | 接到 |
|---|---|
| 1 | 3V3 |
| 2 | GND |
| 3 | I2C_SDA(GPIO5) |
| 4 | I2C_SCL(GPIO6) |

I2C 上拉：SDA/SCL 各 4.7kΩ→3V3（OLED 模块多自带，可做成焊盘选贴）。

---

## 去耦与杂项
- 每个有源器件 VCC 就近 0.1µF；3V3 轨 100µF 体电容。
- 全部 GND 一体地平面（触摸片下方除外，那里 keepout）。
- 可选：3V3 上一颗电源指示 LED + 1kΩ。

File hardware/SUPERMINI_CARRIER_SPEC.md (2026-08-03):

# ESP32-C3 SuperMini 载板接口与封装要求

依据目录 `ESP32C3-Supermini-main` 中的尺寸图、原理图和 Altium `PcbDoc` 整理。

## 已确认尺寸

| 项目 | 数值 |
|---|---:|
| 模块最大宽度（含两侧焊盘） | 18.00 mm |
| 模块长度 | 22.50 mm（资料文字写 22.52 mm） |
| 两排焊盘基准间距 | 15.24 mm |
| 每排焊盘数量 | 8 |
| 纵向焊盘节距 | 2.54 mm |

最终封装以资料内 `Hardware/Super Mini-ESP32C3-外形.PcbDoc` 导入后的机械层和焊盘坐标为准，
图片尺寸用于交叉检查。

## 引脚顺序

观察方向：SuperMini 元件面朝上、USB-C 在上、天线端在下。

```text
              USB-C
       ┌─────────────────┐
GPIO5  │ L1           R8 │ 5V / VBUS
GPIO6  │ L2           R7 │ GND
GPIO7  │ L3           R6 │ 3.3V
GPIO8  │ L4           R5 │ GPIO4
GPIO9  │ L5           R4 │ GPIO3
GPIO10 │ L6           R3 │ GPIO2
GPIO20 │ L7           R2 │ GPIO1
GPIO21 │ L8           R1 │ GPIO0
       └──────天线端─────┘
```

本项目用到的脚全部能够从两侧焊盘取得：GPIO1、3、4、5、6、7、10、20、GND，以及按电源方案
选用的 5V/VBUS。

## 供电关系

SuperMini 原理图显示：

```text
USB-C VBUS ──肖特基二极管── VSYS ──板载 3.3V LDO── ESP32-C3
      │
      └────────────────────────────── 5V/VBUS 焊盘
```

开发板资料明确要求外部供电和 USB 不能同时使用。载板设计因此遵守：

1. 首版只使用 SuperMini 自带 USB-C 作为整机电源入口和烧录口；
2. 载板从 SuperMini 的 `5V/VBUS` 焊盘取得 USB 5V；
3. 载板使用自己的 3.3V 稳压器给蜂鸣器、马达、触摸、编码器上拉和 OLED 供电；
4. 载板 3.3V 与 SuperMini 的 3.3V 输出默认不短接，避免两个稳压器并联；
5. 所有电路共地；
6. 若以后加入锂电或主板 USB-C，必须增加明确的电源选择/隔离，不能同时向 5V/VBUS 灌电并插
   SuperMini USB。

首板画完后应实测 USB 供电时 `5V/VBUS` 焊盘电压，并检查蜂鸣器+马达同时工作时的压降。

## 手焊封装策略

SuperMini 是唯一的后焊件。载板做一个自定义 `ESP32C3_SUPERMINI_HAND_SOLDER` 封装：

- 两排 8 个连接位，中心距 15.24 mm、节距 2.54 mm；
- 载板焊盘向模块外侧加长，保证模块平放后烙铁仍能从外侧接触焊盘；
- 同时保留与模块通孔对应的钻孔，允许使用短排针加固或返修；
- 丝印明确标出 `USB`、`ANT`、`5V`、`GND`、`GPIO0`、`GPIO21`；
- USB-C 插拔方向不得被主板边框、外壳或编码器遮挡；
- 模块本体覆盖区内不放任何元件、过孔或高焊点；
- 天线端优先伸出载板边缘；做不到时，天线下方和前方全部禁铜、禁走线、禁放元件；
- GPIO0、GPIO21、EN/复位相关调试需求可通过模块自身按键和额外测试点处理；
- 在正式投板前，用 1:1 打印的封装图与实物叠放检查。

## 载板原理图符号建议

不要用两个没有语义的 `Header 8`。建立一个 16 引脚模块符号，脚名与上述真实引脚一致。这样 ERC、
BOM 排除和装配图都更清楚。

该器件属性设置为：

- `DNP / Do not populate`；
- 不进入嘉立创贴片 BOM/CPL；
- 装配说明标记 `USER HAND SOLDER AFTER PCBA`。

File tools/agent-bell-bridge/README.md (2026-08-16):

# AgentBell Bridge — 通知自动转发（免 hook）

Windows 托盘常驻小程序：**Claude / Codex 等桌面应用一发系统通知，就自动转发给局域网里的
AgentBell 设备**（蜂鸣 + 震动 + OLED 屏显）。不用再给每个智能体装 Stop hook / notify 脚本。

```
 Claude 桌面版 ─┐ 系统通知                       ┌────────────────────┐
 Codex        ─┤ ────────▶ Windows 通知中心 ───▶ │ AgentBell Bridge    │ ──POST /notify──▶ 🔔 AgentBell
 其它应用      ─┘            (UserNotification    │ 托盘常驻 · 自动发现   │
                             Listener 轮询)      └────────────────────┘
```

原来的 hook 方案（`tools/agent-bell/`）依然可用，两者互不冲突；
Bridge 的优势是**装一次全局生效**，且能看到所有会发系统通知的应用。

---

## 安装（3 步）

1. 双击 [install.bat](install.bat)（装依赖 + 注册开机自启 + 立即启动）。
2. 允许通知访问：`设置 > 隐私和安全性 > 通知 > 让应用访问通知` 打开总开关
   （设置窗口里有「打开通知权限设置」直达按钮；改完权限重启一次 Bridge）。
3. 确认 Claude / Codex 桌面版自己的通知没被关（它们得先发通知，Bridge 才有的转）。

托盘出现 🔔 图标即在运行：**绿点 = 设备在线，红点 = 离线**。
左键双击图标打开设置窗口；卸载运行 [uninstall.bat](uninstall.bat)。
（macOS 上图标在顶部菜单栏、不在 Dock 里，见下面的 macOS 版一节。）

## 自动发现（断连自愈）

按快到慢四级查找：

1. **UDP 广播**问 47317（固件里有应答器）——实测 **0.21 秒**，IP 变了也能找到
2. 缓存的上次 IP（老固件没有广播应答器时靠它）
3. **自己发 mDNS 组播**（UDP 5353，不走系统 DNS）
4. 子网扫描（**最后手段**）：先扫缓存 IP 所在的 /24，再扩到其它网卡

> **为什么把子网扫描压到最后**：实测它不只是慢——254 路并发 TCP/ARP 突发会把设备
> 自己的响应延迟推过客户端超时，漏检率空闲时 5%、风暴中 20%、**风暴停止 2 秒后仍有 33%**。
> 也就是说扫描器会把它要找的设备打趴，然后报告「没找到」。日志里那个「扫描未找到」
> 紧接着「缓存地址可用」的自相矛盾顺序，正是这个自伤的指纹。

> **为什么不用 `gethostbyname("agent-bell.local")`**：装了 Clash 一类 TUN 代理时，`.local`
> 会被 fake-ip 劫持到 198.18.0.0/15 再被 RST（实测 0.02 秒返回失败），而且**任何**域名都能
> "解析成功"，连"没有 mDNS"都判断不了。设备自己的 mDNS 应答是好的，所以绕过系统解析直接发组播。

> 扫描排除：198.18/15（TUN fake-ip）、100.64/10（CGNAT/Tailscale）、169.254/16（link-local）、
> 172.17/16（Docker）、240.0.0.0/4（顺带挡住被正则捞成地址的子网掩码）。
> 网卡枚举有三重来源（`gethostname` / 路由源探测 / `ipconfig`）——前两者在 TUN 环境下都会
> 失灵（路由源探测实测返回 `198.18.0.1`），漏光了会导致「0.01 秒就报未找到」这种假故障。

**实测自愈耗时**：缓存 IP 失效（换路由器 / DHCP 重分配）→ **0.28 秒**（改之前 ~90 秒、扫三轮）。

## 多台电脑连同一台设备

设备端的 Arduino WebServer **一次只服务一个 HTTP 请求**（listen backlog 只有 4），
并发请求会互相把对方顶穿超时。所以客户端这边做了三件事：

- **按设备串行化**（`device_api.py`）：同一台设备的请求排队 + 最小间隔 250ms。
  注意单台电脑本身就有三路请求（设备守护线程 / 通知转发线程 / 面板线程），
  不排队的话自己先跟自己撞。
- **抖动错开**：探活间隔 30 秒 ±20% 随机，多台电脑不会卡在同一刻。
- **合并端点**：面板改用固件的 `/api/state`（info+settings+notes 一次拿完），
  且只在窗口可见时轮询（藏在托盘里就完全不打设备）。

实测 3 台电脑同时连一台设备：改之前失败率 30.8%，改之后 **0%**（请求量 0.72→0.26 req/s）。

## 陌生网络一键配网（provision.py）

带设备去新环境（新 WiFi，手边没有烧录条件）时用。设备连不上旧 WiFi 会在开机约 20 秒后
自动开热点 `AgentBell-XXXX`（也可在设备菜单选「重新配网」立即开）。然后在电脑上跑：

```bash
python provision.py
```

它会自动完成：读出本机 WiFi 名和密码（`netsh`，没连 WiFi 就从已保存网络里选）→
扫到设备热点 → 临时切过去把凭据 POST 给设备 → 电脑切回原 WiFi → 等设备上线并写入
Bridge 的 IP 缓存。之后 Bridge 一启动就能用。

- 手动指定要配的网：`python provision.py --ssid 名称 --pass 密码`
- 没有电脑也行：手机连 `AgentBell-XXXX`（密码 `agentbell`），弹出的页面里填 WiFi 即可
  （没弹就浏览器开 `192.168.4.1`）。
- 设备只支持 **2.4GHz**；密码配错设备会退回配网热点，重跑一次即可。
- 凭据存设备 NVS，优先于固件里编译进去的 `secrets.h`；回到老家网络无需操作（NVS 里存的
  就是老家 WiFi 时）或重配一次。

## 设置窗口

无边框「TE 铝面板」风格固定尺寸窗口（pywebview + WebView2 渲染 `ui/index.html`，
与设备自带网页控制台同一套设计语言，见仓库根 `DESIGN.md`）。标题栏可拖动窗口，
× 键收进托盘（后台继续转发），– 键最小化。

- **显示屏**（左上深色块）：设备在线/离线/扫描进度、通知监听权限状态、信号与运行时长。
- **链路按键**：发测试通知、重新搜索、通知权限直达；手动地址输入 + 连接。
- **转发规则**：总开关；应用关键词（默认 `claude, codex`，按应用显示名匹配，不分大小写）；
  轮询间隔；响铃冷却（一批通知只响一次）。
- **最近通知**：设备上最近响过的通知列表（与设备网页控制台同源）。
- **设备设置**（右栏，设备在线时可用）：蜂鸣/震动/勿扰开关、音量与震动强度推子、
  提示音步进器+试听/试震、操作反馈模式、旋钮方向与灵敏度、待机屏左右模块、通知亮屏。
  改动即时写入设备 flash，与设备上旋钮改的是同一份设置。
- **本程序**：开机自启开关、查看日志、退出。

## 已知限制

- Windows 通知监听对非打包 Python 进程**只能轮询**（默认 2 秒），不能事件推送——
  这是系统限制（`NotificationChanged` 事件需要应用包身份）。
- **应用必须真的发系统通知**才转发得了。Claude 桌面版在窗口失焦时发通知；
  如果你盯着窗口看，它一般不发（这种时候你人就在电脑前，也不需要它响）。
- 若应用通知开了「横幅但不进通知中心」以外的奇怪组合，以通知中心里能看到为准。

## 文件

| 文件 | 作用 |
|---|---|
| `bridge.py` | 主程序：托盘 + pywebview 设置面板 + 线程编排 |
| `ui/index.html` | 设置面板前端（TE 铝面板风格；浏览器直接打开走 mock 数据可预览）|
| `watcher.py` | 通知中心轮询 + 过滤 + 转发（Windows，WinRT）|
| `watcher_mac.py` | 同上的 macOS 实现（轮询通知中心 SQLite 库，接口一致）|
| `discovery.py` | 设备发现（缓存 IP → mDNS → 网段扫描）|
| `device_api.py` | 设备 API 客户端（/api/info /api/settings /api/notes /api/test）|
| `bridge_config.py` | 配置读写（`%APPDATA%\AgentBell\config.json`）|
| `provision.py` | 陌生网络一键配网（读本机 WiFi → 连设备热点推凭据 → 等上线写缓存）|
| `probe_listener.py` | 开发用：验证通知监听可用性 |

日志：`%APPDATA%\AgentBell\bridge.log`。

## 依赖

Python 3.9–3.14（本机 3.12 实测）+ `pystray` `pillow` `pywebview` + `winrt-*` 系列（见 install.bat）；
系统需有 WebView2 运行时（Win11 自带，Win10 一般随 Edge 已装）。
固件需带 `/api/*` 端点的版本（本仓库 `agent_bell/` 当前源码即是）；
老固件只有 `/notify`，转发仍可用，但设备设置区不可用、发现只能靠 mDNS/缓存。

## 打包成安装程序（给别的电脑用，目标机免装 Python）

```sh
# 1) 生成图标 + PyInstaller 打包（onedir，杀软误报少）
python pack/make_icon.py
python -m PyInstaller pack/AgentBellBridge.spec --noconfirm --distpath pack/dist --workpath pack/build
# 2) Inno Setup 出安装器（需装 Inno Setup 6 + 中文语言包）
"%LOCALAPPDATA%/Programs/Inno Setup 6/ISCC.exe" pack/AgentBellBridge.iss
# 产物：pack/Output/AgentBellBridge-Setup.exe（~15MB，单用户安装，无需管理员）
```

安装器特性：可选开机自启（与程序内开关同一注册表键）、卸载先杀进程并清自启项、
配置和日志留在 `%APPDATA%\AgentBell`（重装保留缓存的设备 IP）。

装到新电脑后要做的唯一一件事：Windows 设置 > 隐私和安全性 > 通知 >
「让应用访问通知」里允许 AgentBellBridge（打包后身份不再是 Python，需重新授权一次），
然后重启程序。设置窗口顶部有直达按钮。

打包版注意（spec 里已处理，改代码时别破坏）：winrt 模块化包、pystray._win32、
webview.platforms.winforms/edgechromium 都是运行时动态导入，必须保留在 hiddenimports
列表里；`ui/` 目录要在 datas 里带上（运行时经 `sys._MEIPASS` 定位）。

## macOS 版

同一份代码直接支持 macOS（12+）：通知监听换成轮询「通知中心」数据库
（`watcher_mac.py`），自启用 `~/Library/LaunchAgents`，界面/发现/转发与
Windows 完全一致。

**只驻留菜单栏，不进 Dock**（accessory 应用）：点顶部菜单栏的铃铛图标弹出菜单，
第一项「打开设置」就是面板；面板的 × 收回菜单栏，后台继续转发；退出走菜单里的
「退出」或面板的「退出程序」。

> 实现上必须两处配合：`.app` 的 `Info.plist` 带 `LSUIElement=true`（启动那一刻就没有
> Dock 图标），**加上**运行时把 NSApp 活动策略设回 Accessory——因为 pywebview 的 cocoa
> 后端在导入时会把策略改成 Regular，Dock 图标会冒出来。见 `bridge.py` 的 `_mac_accessory()`；
> CI 里有一步断言构建产物的 `LSUIElement` 为 true，别把它删了。
> 菜单栏图标万一创建失败，程序会自动恢复 Dock 图标并亮出窗口兜底（否则用户没有任何入口）。

**构建**（.app 只能在 Mac 上打，不能在 Windows 交叉编译）：

```sh
cd tools/agent-bell-bridge && bash pack/build_mac.sh
# 产物：pack/Output/AgentBellBridge-mac-<架构>.dmg（applesilicon / intel）
```

**安装与授权**（目标 Mac 上）：

1. 打开 DMG，把 `AgentBell Bridge.app` 拖进「应用程序」。
2. 首次启动用 **右键 → 打开**（应用未签名，直接双击会被 Gatekeeper 拦）。
3. **系统设置 > 隐私与安全性 > 完全磁盘访问权限** 里加入并勾选本 App，
   然后重启它——读通知中心数据库必须此权限（面板顶部「通知权限」按钮直达该页）。
4. 开机自启在设置面板里打开；确认 Claude / Codex 的系统通知没被关。

**源码直接跑**（免打包）：`python3 -m pip install pywebview pystray pillow`
后 `python3 bridge.py`（首次运行给终端/解释器授完全磁盘访问权限即可）。

已知差异：窗口关闭 = 收进菜单栏；无边框窗口没有最小化（mac 上 `–` 键隐藏，
按菜单栏图标唤回）。**注意：macOS 版尚未在真机验证过**——通知库解析逻辑有
跨平台单测护着、`.app` 的菜单栏驻留配置由 CI 断言，但 pywebview/权限流程需要在
Mac 上实测，问题看 `~/Library/Application Support/AgentBell/bridge.log`。

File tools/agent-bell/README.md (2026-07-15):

# AgentBell 电脑侧通知器

当 **Claude Code / Codex** 完成一轮对话时，给局域网里的 AgentBell 设备发一条 HTTP 通知，
让它蜂鸣 + 震动 + 在 OLED 上显示「哪台电脑 / 哪个智能体 / 哪个对话」完成了。

- **纯 Python 标准库**，无需 `pip install` 任何东西。
- 三个脚本：
  - `notify.py` — 核心发送器（也可命令行直接用）。
  - `claude_stop_hook.py` — 挂在 Claude Code 的 `Stop` hook 上。
  - `codex_notify.py` — 挂在 Codex 的 `notify` 上。
- **永不阻塞智能体**：设备没开机 / 掉线时静默忽略，脚本总是成功退出。

---

## 1. 设备地址

脚本按这个顺序找设备：`--host` 参数 → 环境变量 `AGENT_BELL_HOST` → 默认 `agent-bell.local`（mDNS）。

大多数情况下 mDNS 直接可用，无需配置。若解析不了（部分 Windows 网络环境），
把设备**开机时 OLED 上显示的 IP** 设进环境变量：

```powershell
# Windows（永久，重开终端生效）
setx AGENT_BELL_HOST 192.168.1.23
```
```bash
# bash / macOS / Linux（当前会话）
export AGENT_BELL_HOST=192.168.1.23
```

---

## 2. 先自测（确认设备能响）

设备烧好、连上 WiFi 后，任选其一：

```bash
python tools/agent-bell/notify.py --demo
# 或浏览器打开控制台 http://agent-bell.local/ ，登录后点「发一条测试通知」
```

设备应当立刻蜂鸣 + 震动，并显示一条测试通知。控制台 `http://agent-bell.local/`（需登录，
用户名/密码在固件 `WEB_USER`/`WEB_PASS`）还能开关蜂鸣器/震动/勿扰、看 IP 与最近通知列表。

---

## 3. 接 Claude Code

把下面的 `Stop` hook 加进配置。二选一：

- **全局**（推荐，所有项目结束对话都通知）：`~/.claude/settings.json`
  （Windows 是 `C:\Users\你的用户名\.claude\settings.json`）
- **仅本项目**：仓库里的 `.claude/settings.json`（本仓库已内置一份作示例）

```json
{
  "hooks": {
    "Stop": [
      {
        "hooks": [
          { "type": "command",
            "command": "python \"D:\\开发板玩法\\agent-bell\\tools\\agent-bell\\claude_stop_hook.py\"" }
        ]
      }
    ]
  }
}
```

> 路径按你的实际位置改；JSON 里反斜杠要写成 `\\`。
> 若 `python` 不在 PATH 上，把命令里的 `python` 换成 Python 绝对路径（如
> `C:\Users\你\AppData\Local\Programs\Python\Python312\python.exe`）。

---

## 4. 接 Codex

编辑 `~/.codex/config.toml`（Windows：`C:\Users\你的用户名\.codex\config.toml`），加一行：

```toml
notify = ["python", "D:\\开发板玩法\\agent-bell\\tools\\agent-bell\\codex_notify.py"]
```

Codex 每轮结束会把事件 JSON 作为最后一个参数传给它；脚本只处理 `agent-turn-complete`。

---

## 5. 手动 / 脚本里发通知

```bash
python tools/agent-bell/notify.py \
    --agent Claude --conversation agent-bell --message "编译通过" \
    --computer 书房台式 --host 192.168.1.23
```

字段（都可选，`--agent`/`--conversation` 最有用）：`--agent`（智能体名）、
`--conversation`（对话/项目名）、`--message`（摘要）、`--computer`（默认取本机主机名）、
`--host`/`--port`、`--level`（预留）、`--timeout`（默认 1.5s）。

中文会自动 URL 编码传输，设备端解回 UTF-8 显示；过长字段按 UTF-8 边界安全截断。

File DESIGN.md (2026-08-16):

# AgentBell 设计语言 — TE 铝面板（两端共享契约）

> 适用范围：`tools/agent-bell-bridge/`（Windows 桥接程序设置窗）与 `agent_bell/agent_bell.ino` 内嵌网页控制台。
> 两端是"同一台仪器的两块面板"：控件造型、配色、字重必须同构；平台差异（触屏目标尺寸、DPI 缩放）允许各自适配。

## THESIS

电脑端与设备网页端读起来是同一件硬件的延伸——浅暖灰铝面板、拟物控件、全页唯一深色块是"显示屏"。
拒绝类目默认：暗色 dashboard、圆角卡片堆、彩色粗左边框、eyebrow 标签。

## 令牌（两端一致，十六进制不许漂移）

| 令牌 | 值 | 用途 |
|---|---|---|
| CHASSIS | `#E4E3DF` | 机身/页面底色（浅暖灰铝） |
| LINE | `#C6C5C0` | 分区细线 |
| EDGE_HI | `#F2F1EE` | 机加工内侧高光线（装饰，可选） |
| INK | `#1D1C19` | 主文字 |
| MUTED | `#605F58` | 次要文字（对 CHASSIS 实测 4.99:1；旧 `#8B8A84` 只准用于禁用态/装饰） |
| ORANGE | `#F04E00` | **唯一强调色**：推子填充、拨钮开态、主按钮、焦点框 |
| ORANGE_DK | `#C84100` | 橙按压/描边 |
| KEY_BG / KEY_HI / KEY_DN | `#F6F5F2` / `#FFFFFF` / `#DDDCD7` | 键帽面 / 悬停 / 按下 |
| KEY_EDGE | `#AFAEA8` | 键帽描边 |
| DISP_BG / DISP_EDGE | `#141412` / `#2A2A26` | 显示屏底（全页唯一深色块）/ 屏框 |
| DISP_FG / DISP_DIM | `#EDEBE3` / `#807E75` | 屏内主字 / 暗字 |
| GREEN / RED / AMBER | `#3FB950` / `#E5484D` / `#E8A33D` | 在线 / 离线错误 / 搜索警告 |

## 控件语言

- **区块标题**：大写小字号拉字距标签 + 右侧延伸 1px 细线（LINE）。
- **推子 fader**：2px 轨道 `#B3B2AC` + 橙已填充段 + 竖向滑块帽（KEY_BG 面、3 条防滑纹 `#B0AFA9`）+ 等宽数值。
- **拨钮 toggle**：圆角胶囊轨道（关 `#B7B6B0`，开 ORANGE）+ 白圆滑块。
- **选择器**：雕刻值格显示当前项 + 右侧下拉小箭头，**点击展开全部选项直接选**（桌面=自绘键帽弹层，橙点标当前项，靠底自动向上翻；网页=原生 `select` 样式化，触屏弹系统选择器）。桌面另保留 `‹ ›` 键帽做相邻微调；纯数值参数（轮询/冷却）仍用 `‹ 值 ›` 步进。
- **按钮**：键帽——KEY_BG 面、1px KEY_EDGE 描边、圆角 4–6px、按下整体下沉 1px；主按钮=深橙面（ORANGE_DK，白字 4.99:1 过 AA）白粗体字，悬停亮至 ORANGE。
- **显示屏**：深色圆角块 + 等宽字 + 状态色；网页端保留细扫描线质感（克制）。例外：toast 瞬态提示允许复用屏色（读作"迷你屏"），不算第二个深色块。

## 字体

- 网页端：`system-ui` 正文；`ui-monospace` 标签/数值。
- 桌面端：Microsoft YaHei UI / Segoe UI 正文；Consolas 等宽。

## 形态

- 桌面端：无边框固定尺寸横向面板（pywebview/WebView2 渲染 `tools/agent-bell-bridge/ui/index.html`，逻辑 1120×660，DPI 由 WebView2 自适配），自绘标题栏（字标 + 铭牌 + 状态 LED + – 最小化 + × 键帽收托盘，整条可拖动）、四角装饰螺丝、Win11 DWM 圆角机身。
- 网页端：max-width 480px 手机优先；顶部字标 + `console-1` 铭牌 + 状态 LED；OLED 仿真屏为视觉锚点；触屏目标 ≥44px。

## 措辞对照（两端必须逐字一致）

| 含义 | 定稿措辞 |
|---|---|
| 通知点亮屏幕 | 通知亮屏（熄屏自动点亮） |
| 旋钮灵敏度值 | 1 档/步 · 2 档/步 · 3 档/步 |
| 待机屏半屏选择 | 待机屏·左 / 待机屏·右 |
| 试听按钮 | 试听 / 试震 |
| 区块标题 | 双语铭牌式 "NOTIFY · 通知"（英文大写拉字距 + 中文） |

## 图标系统

画法一处定义在 `tools/agent-bell-bridge/pack/icon_art.py`，三个用途同一套铃铛几何
（半圆罩 + 外张裙摆 + 收边横条 + 锤点，22 单位网格），所以看起来是一家人。

| 用途 | 画法 | 为什么 |
|---|---|---|
| 应用图标（Dock/任务栏/安装器）| 拉丝铝 squircle + 内凹深色屏 + 屏里印 TE 橙铃铛 | 它就是一小块 AgentBell 面板；深浅对比让它在 32px 也立得住 |
| 应用图标 16–24px | 只留橙铃铛，无机身 | 那种尺寸机身会糊成一团 |
| Windows 托盘 | 橙铃铛 + 右下状态点（绿=在线 红=离线）| 托盘允许彩色，状态点是有用信息 |
| macOS 菜单栏 | **模板图**（纯 alpha 单色），在线=实心铃铛 / 离线=空心铃铛 | 模板图由系统按菜单栏明暗自动上色，永远看得见；没有颜色可用，所以用形状区分状态（实测 22pt 下"加斜杠"会糊成一团） |

生成：`python pack/make_icon.py`（.ico，分尺寸画法）、`python pack/make_icns.py`（.icns）。
两个 PyInstaller spec 都要把 `icon_art.py` 带进 `datas`，否则打包版画不出托盘图标。

> macOS 陷阱：pystray 的 `_start_setup()` 在**后台线程**里设图标，而 AppKit 不允许
> 非主线程改 UI —— 菜单栏会只剩一个能点的空白位。必须自己在主线程
> `setImage_`（见 `bridge.py` 的 `_mac_apply_tray`），并给 `run_detached` 传空 setup
> 避免两边打架。

## 模式与底线（Operate）

表达永不遮蔽任务。正文对比度 ≥4.5:1；`:focus-visible` 橙框；`prefers-reduced-motion` 尊重；
中文文案说人话——控件名其动作，错误名其问题与恢复路径。

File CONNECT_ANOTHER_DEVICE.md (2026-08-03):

# 让另一台电脑也连上 AgentBell（多设备接入）

同一个 WiFi 下，**任意台电脑**上的 Claude Code / Codex 都能给这台 AgentBell 发通知。
本文件自包含：照着做即可，不需要拷贝本项目仓库。

## 设备信息

| 项 | 值 |
|---|---|
| 名称（mDNS） | `agent-bell.local` |
| 当前 IP | `192.168.31.133`（DHCP，可能变；建议在路由后台给它绑定固定 IP，见文末） |
| 通知接口 | `POST http://agent-bell.local/notify`（字段 `computer/agent/conversation/message`）|
| 控制台 | `http://agent-bell.local/`（浏览器打开，无需登录）|

前提：**新电脑和设备在同一个 WiFi**（不能是访客网络/开了 AP 隔离），且装了 **Python 3**。

---

## 🤖 如果你是 AI 智能体，照这几步做

1. 确认能连上设备：命令行 `ping agent-bell.local`，或浏览器开 `http://agent-bell.local/`。连不上看文末排错。
2. 新建脚本 `agentbell_notify.py`（内容见下方「脚本」一节），放在一个固定路径，例如：
   - Windows：`C:\Users\<你>\agentbell_notify.py`
   - macOS/Linux：`~/agentbell_notify.py`
3. 若 `agent-bell.local` 解析不了，就设环境变量 `AGENT_BELL_HOST=192.168.31.133`（见下）。
4. 接 Claude Code：把 Stop hook 合并进用户级 `~/.claude/settings.json`（见「接 Claude」）。
5. 接 Codex：把 notify 合并进 `~/.codex/config.toml`（见「接 Codex」）。
6. 自测：`echo {"cwd":"/tmp/demo"} | python3 <脚本路径>` → 设备应"叮咚"+震动+屏显。
7. 重启 Claude Code / Codex 让配置生效。

---

## 脚本 `agentbell_notify.py`

一个文件同时兼容 Claude（Stop hook，读 stdin）和 Codex（notify，读命令行参数）。
纯标准库、绕过代理直连局域网、超时快、**永远静默成功**（设备离线也不拖累智能体）。

```python
#!/usr/bin/env python3
# -*- coding: utf-8 -*-
"""AgentBell 通知器（Claude Stop hook / Codex notify 两用）。"""
import json, os, socket, sys, urllib.parse, urllib.request

HOST = os.environ.get("AGENT_BELL_HOST", "agent-bell.local")
PORT = int(os.environ.get("AGENT_BELL_PORT", "80"))

def clip(s, n):                       # 按 UTF-8 字节安全截断，避免截半个汉字
    b = ("" if s is None else str(s)).encode("utf-8")[:n]
    while b:
        try: return b.decode("utf-8")
        except UnicodeDecodeError: b = b[:-1]
    return ""

def send(agent, conversation, message=""):
    body = urllib.parse.urlencode({
        "computer": clip(socket.gethostname(), 22),
        "agent": clip(agent, 14),
        "conversation": clip(conversation, 46),
        "message": clip(message, 78),
    }).encode("utf-8")
    req = urllib.request.Request("http://%s:%d/notify" % (HOST, PORT), data=body, method="POST")
    op = urllib.request.build_opener(urllib.request.ProxyHandler({}))   # 局域网直连，绕过系统代理
    try:
        op.open(req, timeout=1.5)
    except Exception as e:
        sys.stderr.write("[agent-bell] 发送失败（已忽略）：%s\n" % e)

def main():
    if len(sys.argv) > 1:                      # Codex：事件 JSON 作为最后一个参数
        try: d = json.loads(sys.argv[-1])
        except Exception: return
        if d.get("type") != "agent-turn-complete": return
        cwd = d.get("cwd")
        conv = os.path.basename(os.path.normpath(cwd)) if cwd else "Codex 会话"
        send("Codex", conv, d.get("last-assistant-message") or "")
        return
    try:                                       # Claude：Stop 事件 JSON 从 stdin 进
        d = json.loads(sys.stdin.buffer.read().decode("utf-8"))
    except Exception:
        d = {}
    cwd = d.get("cwd") or os.getcwd()
    send("Claude", os.path.basename(os.path.normpath(cwd)) or "-", "")

if __name__ == "__main__":
    try: main()
    except Exception: pass
    sys.exit(0)                                # 永远成功退出
```

---

## 设备地址（可选）

默认用 mDNS 名 `agent-bell.local`，多数情况直接可用。若解析不了，设环境变量指向 IP：

```powershell
# Windows（永久，重开终端生效）
setx AGENT_BELL_HOST 192.168.31.133
```
```bash
# macOS / Linux（写进 ~/.zshrc 或 ~/.bashrc 持久化）
export AGENT_BELL_HOST=192.168.31.133
```

---

## 接 Claude Code

编辑用户级 `~/.claude/settings.json`（Windows：`C:\Users\<你>\.claude\settings.json`），
**合并**下面的 `Stop` hook（保留文件里已有的其它内容，别整体覆盖）：

```json
{
  "hooks": {
    "Stop": [
      { "hooks": [
        { "type": "command", "command": "python3 \"<脚本完整路径>\"" }
      ] }
    ]
  }
}
```

- Windows 把 `python3` 换成 `python`，路径用双反斜杠，如
  `"command": "python \"C:\\Users\\你\\agentbell_notify.py\""`。
- 只想本项目通知，就把它放进该项目的 `.claude/settings.json` 而不是用户级。

---

## 接 Codex

编辑 `~/.codex/config.toml`（Windows：`C:\Users\<你>\.codex\config.toml`），加一行：

```toml
notify = ["python3", "<脚本完整路径>"]
```

Windows 用 `["python", "C:\\Users\\你\\agentbell_notify.py"]`。Codex 每轮结束会把事件 JSON 作为最后一个参数传入，脚本只处理 `agent-turn-complete`。

---

## 自测

```bash
# 模拟一次 Claude 结束（应触发设备"叮咚"+震动+屏显）
echo '{"cwd":"/tmp/demo-project"}' | python3 <脚本完整路径>
# 或直接浏览器打开，让设备自己发一条测试：
#   http://agent-bell.local/api/test
```

设备响了就成功。之后随便跑一轮真实对话，结束时就会自动通知。

---

## 连不上？排错

1. **不在同一 WiFi / 访客网络**：确认两台设备连的是同一个路由的同一个（非访客）SSID。
2. **AP 隔离**：有些路由（尤其访客网络）开了"AP 隔离/设备隔离"，会挡住设备间互访 —— 在路由后台关掉，或把两者放同一主网络。
3. **`agent-bell.local` 打不开**：改用 IP（`http://192.168.31.133/`）；并设 `AGENT_BELL_HOST` 为该 IP。
4. **IP 变了**：DHCP 可能重新分配。看设备**控制台首页**或**待机屏顶栏**上的当前地址；一劳永逸的办法是下一节固定 IP。
5. **公司电脑有代理**：脚本已用 `ProxyHandler({})` 绕过代理直连，通常无需额外设置。

---

## 建议：给设备固定 IP（防掉线）

在路由后台（如小米路由 `192.168.31.1` → 常用设置 → DHCP/IP 绑定 / 静态分配）里，
把设备的 MAC 绑定成一个固定 IP（如 `192.168.31.133`）。这样重启/过期后地址不变，
`AGENT_BELL_HOST` 或书签就一直有效。设备 MAC 可在控制台首页或路由的已连接设备列表里看到。

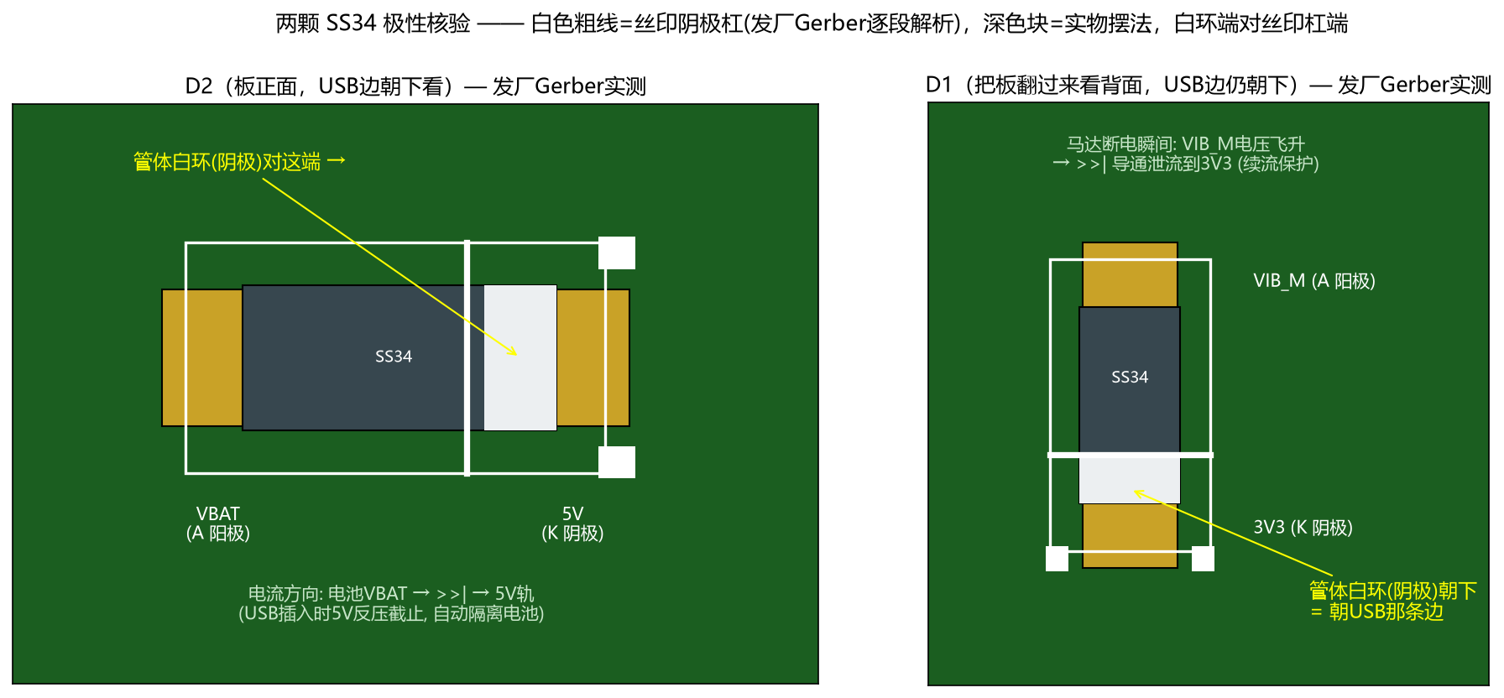
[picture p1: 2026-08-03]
hardware/下单文件-20260729/SS34极性核验图.png

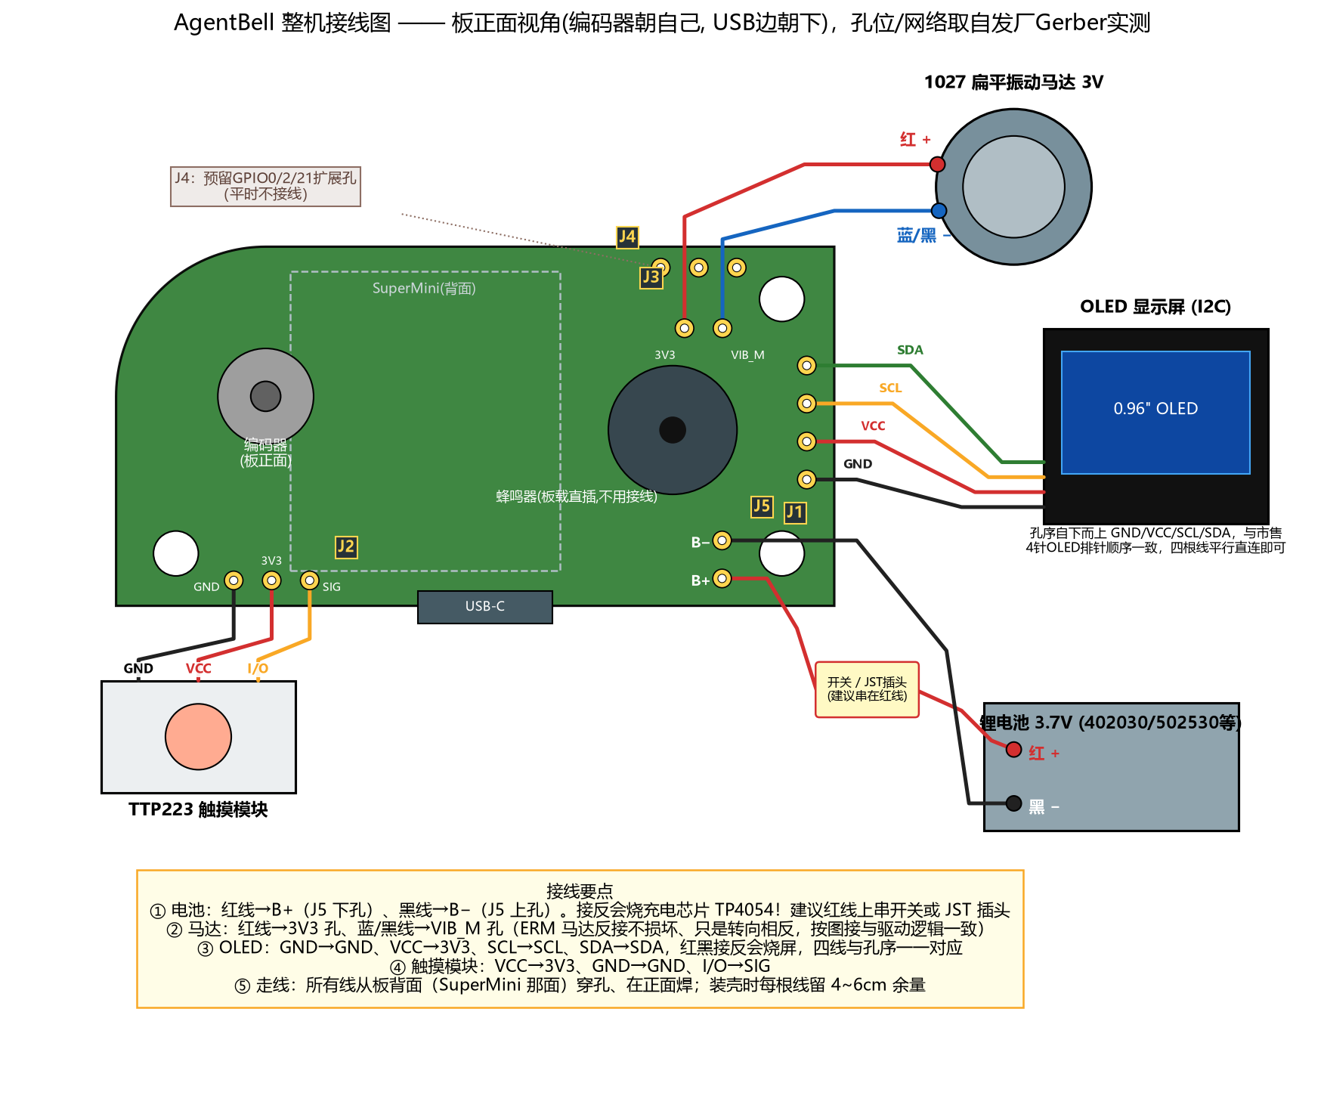
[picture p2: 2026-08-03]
hardware/下单文件-20260729/整机接线图.png

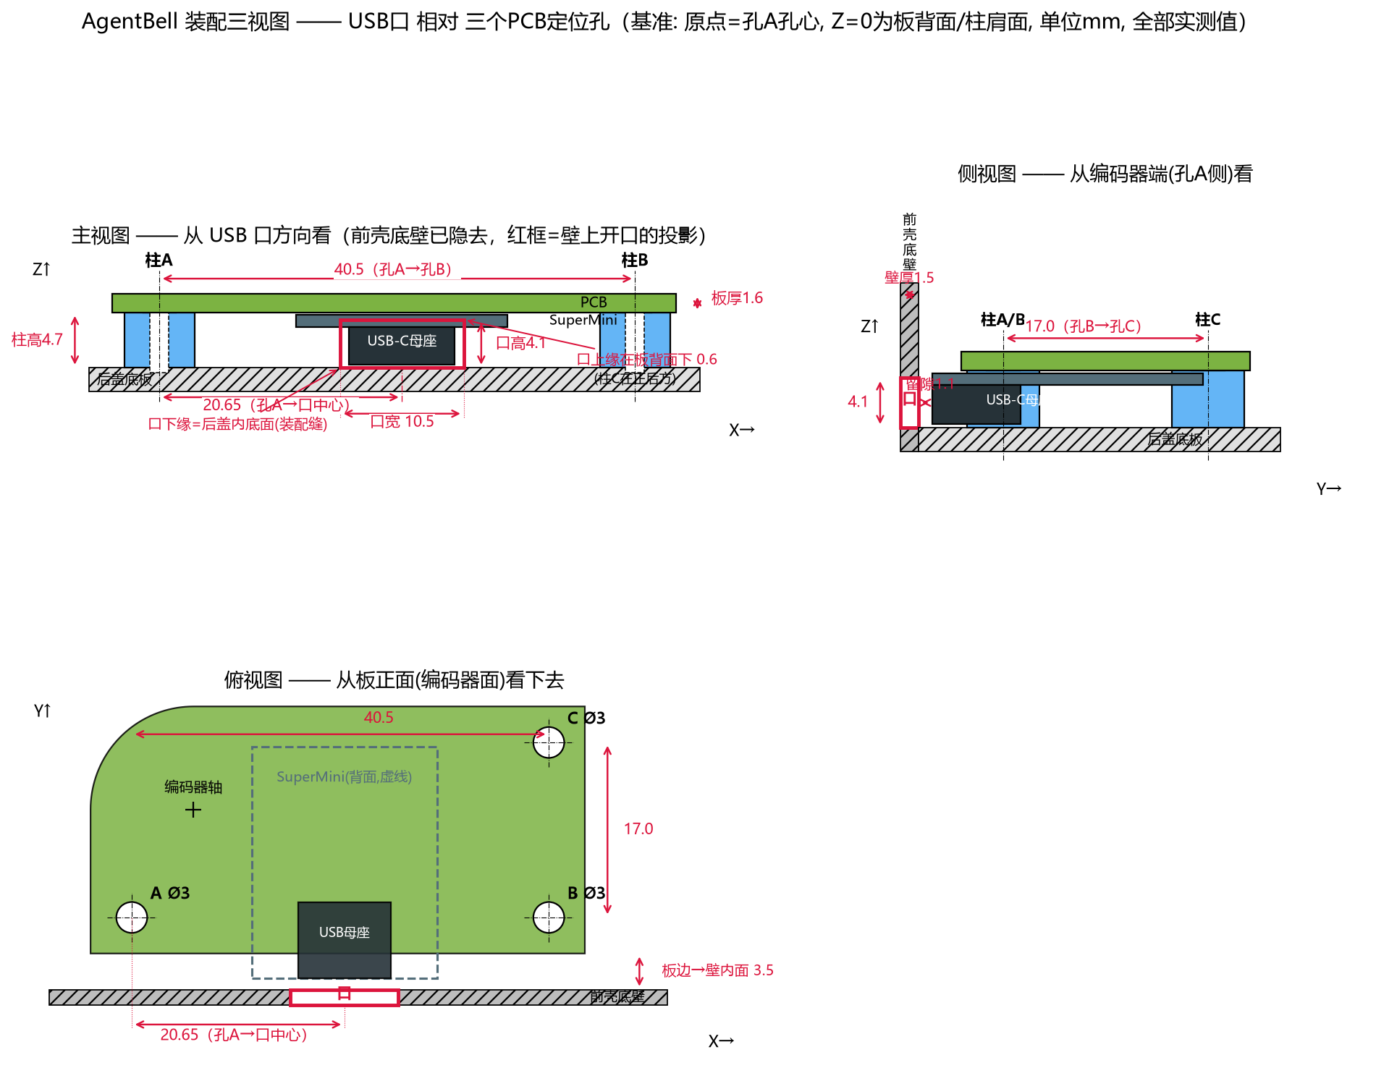
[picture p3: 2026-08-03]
外壳/三视图-USB口与定位孔.png

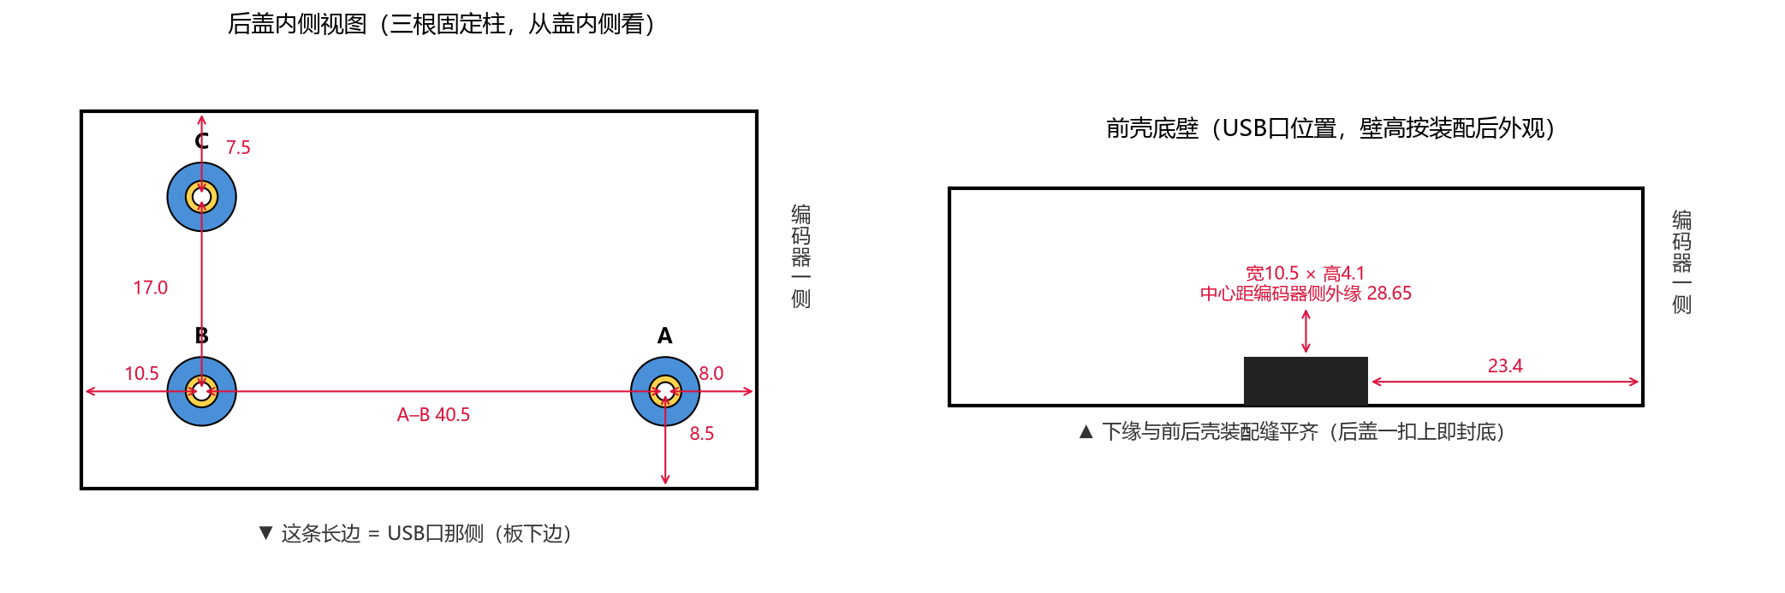
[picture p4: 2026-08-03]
外壳/尺寸图-固定柱与USB口.png

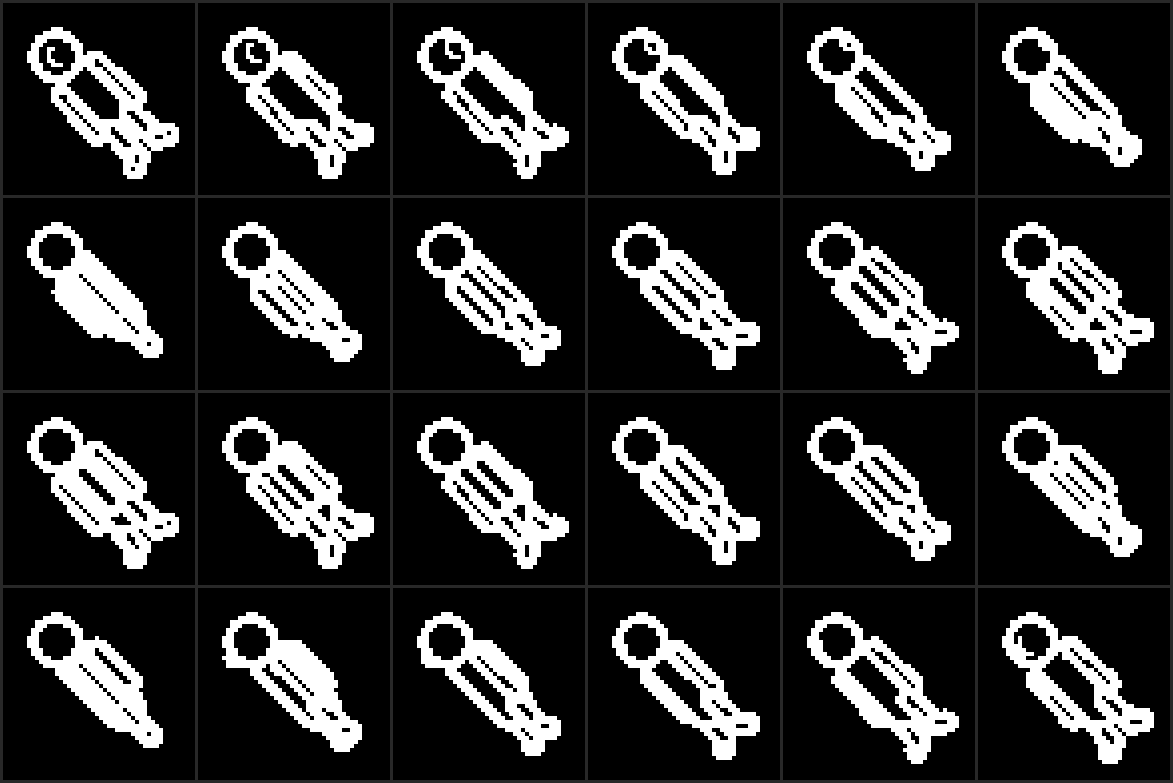
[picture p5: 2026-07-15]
tools/astro_preview.png

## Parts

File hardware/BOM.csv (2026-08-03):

Comment | Designator | Footprint | LCSC | Note
BQ24074RGTR 充电与电源路径 | U1 | QFN-16-EP_3x3 | C54313 | SMT·正式候选·USB优先/边充边用/单节4.2V锂电
AP2112K-3.3 LDO | U2 | SOT-23-5 | C51118 | SMT·外设3.3V·输入接后级5V_SYS
TTP223-BA6 触摸IC | U3 | SOT-23-6 | C80757 | SMT·Extended
SS8550 PNP | Q1 | SOT-23 | C8542 | SMT·Basic·蜂鸣器低有效驱动
SS8050 NPN | Q2 | SOT-23 | C2150 | SMT·Basic·马达高有效驱动
1N4148W 二极管 | D1 | SOD-123 | C81598 | SMT·马达续流(阴极朝3V3)
MLT-5020 小型无源蜂鸣器 | LS1 | SMD-5.2x5.2 | C94598 | SMT·Extended·2~4V·100mA·75dB·4kHz·小型化候选
SMD币式振动马达 LCM1027A3670F | M1 | SMD | C22359894 | SMT·Extended·3V/80mA·JLC注明需要装配治具
EC05E1220401 薄型旋转编码器 | SW1 | EC05-SMD | C116648 | SMT·Extended·约7.6x6.2x2.7mm·中空轴·待机械确认
EVQ-P7K01P 小型确认键 | SW3 | KEY-SMD_3.5x2.9 | C5736840 | SMT·Extended·替代EC11内置按压·接GPIO20
TPS61023DRLR 5V升压 | U4 | SOT-563 | C919459 | SMT·Extended·1.6x1.2mm·同步升压·负载断开·待功率核算
SPDT滑动开关 SK-12D07 | SW2 | SK-12D07 | C431540 | SMT·控制后级电源EN·OFF仍可充电
USB-C 16P(主板充电/供电) | J1 | TYPE-C-31-M-12 | C165948 | SMT·主日常接口·仅USB2电源输入
JST-PH2.0 2P/3P(锂电) | J2 | JST-PH-2P | C131337 | SMT·等待电池线数/极性/NTC后定版
4P防呆SMD座(OLED排线) | J3 | SMD-4P |  | SMT·待选板端座+配套线壳端子·确认屏幕线序
ESP32-C3 SuperMini载板焊盘 | MOD1 | CUSTOM_2X8_15.24MM |  | ★唯一手焊件·DNP·不进入JLC贴片BOM/CPL
LED红0805(充电中) | D2 | LED0805 | C2286 | SMT·核对
LED绿0805(充满) | D3 | LED0805 | C72043 | SMT·核对
电阻1k | R1;R3;R12;R13 | R0402 | C11702 | SMT·Basic(蜂鸣/马达基极+LED限流)
电阻10k | R2;R9;R10;R11 | R0402 | C25744 | SMT·Basic(基极上拉+编码器上拉)
充电/输入限流/终止电阻 | R4;R14;R15 | R0402 |  | SMT·数值按电池容量和BQ24074数据手册计算后锁定
电阻5.1k | R5;R6 | R0402 | C25905 | SMT·Basic·USB-C CC下拉
电阻4.7k | R7;R8 | R0402 | C25900 | SMT·Basic·I2C上拉(OLED自带则选贴)
电容0.1uF | C7;C8;C9 | C0402 | C1525 | SMT·Basic·去耦(TTP223/通用/编码器SW)
电容10nF | C10;C11 | C0402 | C1523 | SMT·编码器A/B去抖·核对
电容1uF | C3;C4 | C0402 | C52923 | SMT·LDO进出·核对
电容10uF | C1;C2 | C0603 | C19702 | SMT·BQ24074 IN/OUT或BAT去耦·按数据手册最终分配
电容22uF | C5 | C0805 | C45783 | SMT·LDO输出·核对
储能电容 | C6 | C0805/C1206 |  | SMT·容量按5V_SYS/3V3瞬态测试确定·优先22~47uF低矮封装
电容Cs(触摸灵敏度) | C12 | C0402 |  | DNP·默认不贴=最灵敏

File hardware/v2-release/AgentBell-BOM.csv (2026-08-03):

No. | Quantity | Comment | Designator | Footprint | Value | Manufacturer Part | Manufacturer | Supplier Part | Supplier
1 | 1 | CL21A226MAQNNNE | C1 | C0805 |  | CL21A226MAQNNNE | SAMSUNG(三星) | CL21A226MAQNNNE.1 | LCSC
2 | 2 | CC0805KRX7R9BB104 | C2,C4 | C0805 |  | CC0805KRX7R9BB104 | YAGEO(国巨) | CC0805KRX7R9BB104.1 | LCSC
3 | 2 | GRM21BR61H106KE43L | C3,C5 | C0805 |  | GRM21BR61H106KE43L | muRata(村田) | GRM21BR61H106KE43L.1 | LCSC
4 | 2 | SS34 | D1,D2 | SMA_L4.3-W2.6-LS5.2-RD |  | SS34 | MDD(辰达半导体) | SS34_C8678.1 | LCSC
5 | 1 | KT-0805Y | LED1 | LED0805-R-RD |  | KT-0805Y | KENTO | 17-21SUYC/TR8.1 | LCSC
6 | 1 | QMB-09B-03 | LS1 | BUZ-TH_BD9.0-P4.00-D0.6-FD |  | QMB-09B-03 | 华能 | QMB-09B-03.1 | LCSC
7 | 1 | SS8550 Y2(RANGE:200-350) | Q1 | SOT-23-3_L2.9-W1.3-P1.90-LS2.4-BR |  | SS8550 Y2(RANGE:200-350) | CJ(江苏长电/长晶) | SS8550_C8542.1 | LCSC
8 | 1 | AO3400A | Q2 | SOT-23-3_L2.9-W1.3-P1.90-LS2.4-BR |  | AO3400A | AOS | AO3400A.1 | LCSC
9 | 5 | 0805W8F1002T5E | R1,R2,R3,R5,R7 | R0805 |  | 0805W8F1002T5E | UNI-ROYAL(厚声) | 0805W8F1002T5E.1 | LCSC
10 | 2 | 0805W8F1001T5E | R4,R9 | R0805 |  | 0805W8F1001T5E | UNI-ROYAL(厚声) | 0805W8F1001T5E.1 | LCSC
11 | 1 | 0805W8F1000T5E | R6 | R0805 |  | 0805W8F1000T5E | UNI-ROYAL(厚声) | 0805W8F1000T5E.1 | LCSC
12 | 1 | 0805W8F5601T5E | R8 | R0805 |  | 0805W8F5601T5E | UNI-ROYAL(厚声) | 0805W8F5601T5E.1 | LCSC
13 | 1 | EC1106S | SW1 | SW-SMD_EC1106S |  | EC1106S |  | EC1106S.1 | LCSC
14 | 1 | ESP32C3-SuperMini | U1 | COMM-SMD_16P-L22.5-W18.0-P2.54-TL |  | ESP32C3-SuperMini |  | ESP32C3-SUPERMINI.1 | LCSC
15 | 1 | TP4054 | U2 | SOT-23-5_L2.9-W1.6-P0.95-LS2.8-BL |  | TP4054 | RealChip(正芯半导体) | TP4054_C5137090.1 | LCSC

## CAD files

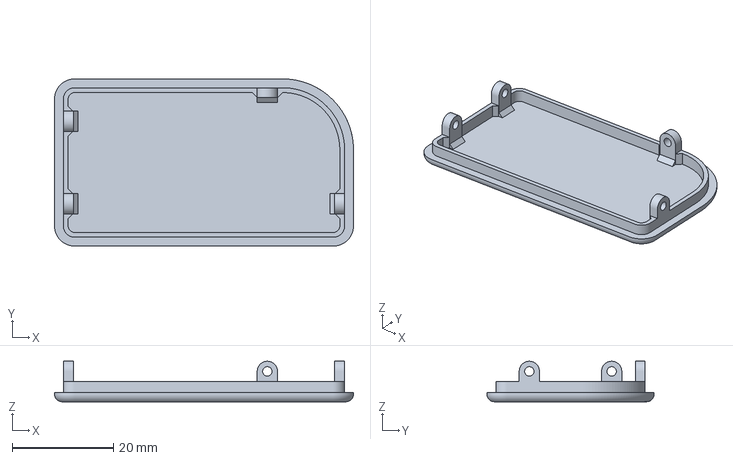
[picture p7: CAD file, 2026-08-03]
外壳/后盖-原版.3mf
59.0 x 33.0 x 8.00 mm

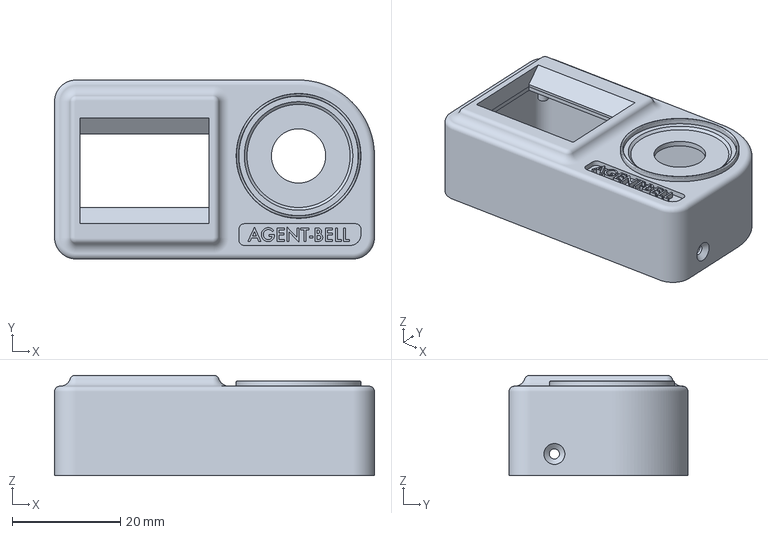
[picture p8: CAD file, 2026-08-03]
外壳/前壳-原版.3mf
59.0 x 33.0 x 18.5 mm

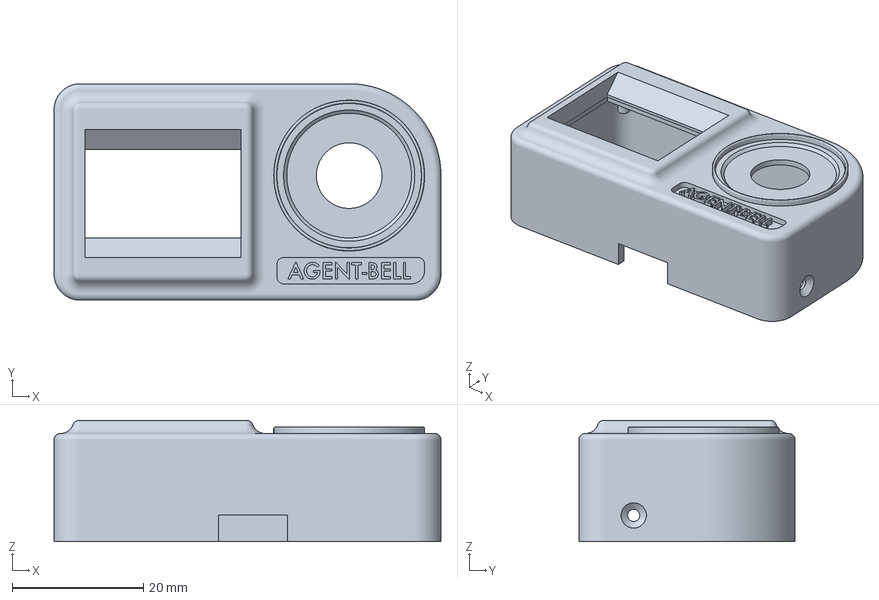
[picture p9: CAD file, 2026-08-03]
外壳/前壳-带USB口-打印用.3mf
59.0 x 33.0 x 18.5 mm

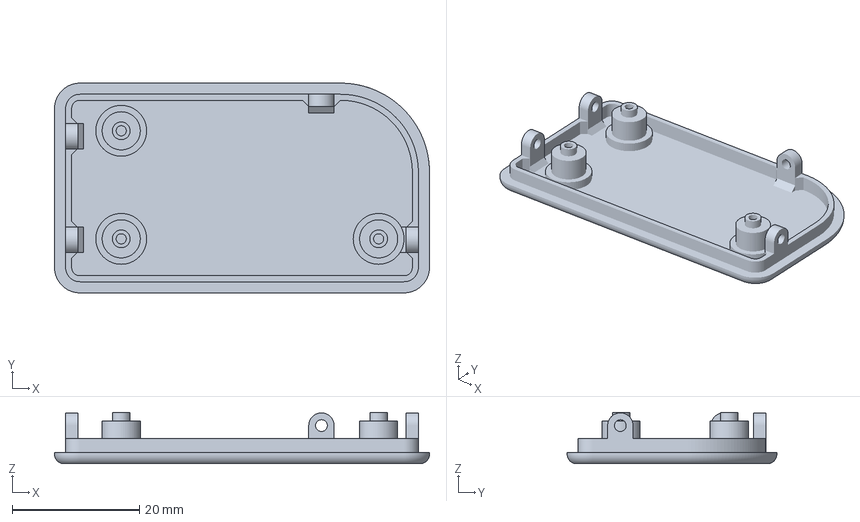
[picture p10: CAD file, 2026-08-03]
外壳/后盖-带固定柱M2-打印用.3mf
59.0 x 33.0 x 8.10 mm

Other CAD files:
外壳/前壳-带USB口-打印用.stl
外壳/后盖-带固定柱M2-打印用.stl

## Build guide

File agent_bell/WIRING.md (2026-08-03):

# AgentBell 接线（ESP32-C3 SuperMini）

固件里用 **GPIO 号**（逻辑通用）；SuperMini 丝印直接标 GPIO 数字。
若换别的板子（XIAO 丝印是 D0–D10 等），照 GPIO 号找对应脚即可，代码不用改。

## 接线表

| 模块 | 模块脚 | 接到 ESP32-C3 | 说明 |
|---|---|---|---|
| **OLED 128×64** | SDA | **GPIO5** | I2C 数据 |
| | SCL | **GPIO6** | I2C 时钟 |
| | VCC | **3V3** | |
| | GND | **GND** | |
| **旋转编码器 HW-040** | CLK | **GPIO1** | A 相 |
| | DT | **GPIO7** | B 相 |
| | SW | **GPIO20** | 按压（低有效）|
| | **+** | **3V3** | ⚠ **绝不能接 5V**（见下）|
| | GND | **GND** | |
| **蜂鸣器（无源）** | I/O | **GPIO3** | 方波驱动发声 |
| | VCC | **3V3** | 弱则改 5V |
| | GND | **GND** | |
| **震动模块** | IN | **GPIO10** | PWM 驱动 |
| | VCC | **3V3** | 弱则改 5V |
| | GND | **GND** | |

## ⚠ 电压：ESP32-C3 不耐 5V

1. **旋转编码器的 `+` 必须接 3V3**：它的 CLK/DT/SW 输出电平跟随供电脚，接 5V 会把 5V 打进
   GPIO 烧芯片。编码器本体无源，3.3V 完全能用（虽然模块标称 5V）。
2. **OLED 的 VCC 也必须 3V3**。
3. **蜂鸣器 / 震动**：先接 3V3。**不要仅因为声音/震动弱就直接把模块 VCC 改接 5V。**
   你提供的蜂鸣器 PDF 是 PNP 高边驱动；这类模块接 5V 时，3.3V GPIO 未必能让驱动管可靠关断，
   还可能通过基极通路影响 GPIO。震动模块也必须先确认驱动电路和输入限流。若要使用 5V，
   应由主 PCB 上的 MOSFET/电平转换电路隔离后再驱动负载。
4. **所有 GND 共地**。

## 旋转编码器调校

- **方向反了**：把 `agent_bell.ino` 顶部的 `// #define ENC_REVERSED` 取消注释，重新烧录。
- **转一档跳好几格 / 跳不动**：调 `ENC_DIV`（默认 4；跳多格就减小，跳不动就增大）。
- **按键**：短按=确认/进入，长按≈0.5s=返回。

## 用法（编码器菜单）

- 待机（太空人）**转动或按一下** → 进主菜单。
- 主菜单：**转**=移动光标（丝滑滚动），**短按**=进入/确认/切换，**长按**=返回上一级/回待机。
- 提示音子菜单：转到某项**停 0.3 秒自动试听**，短按=选用。
- 蜂鸣/震动强度：进去后**转**=调整（即时试声），按=保存返回。
- 菜单里 **15 秒无操作**自动回待机；来通知会打断任何界面并响铃。

## 避坑：strapping 脚

已避开 **GPIO2 / GPIO8 / GPIO9**（板载蓝灯在 8、BOOT 键在 9）。当前用的 1/3/5/6/7/10/20 都是安全脚。

## 蜂鸣器 / 震动极性

蜂鸣器是**无源**的，靠方波发声，无极性开关。震动模块若"常震/不震"，翻 `agent_bell.ino` 顶部
`VIB_ACTIVE_HIGH`。

## OLED I2C 地址

默认 `0x3C`；少数屏是 `0x3D`。不亮就改 `agent_bell.ino` 里的 `OLED_ADDR`。

## 🔒 麦克风（以后录音用）

原预留的 GPIO7 / GPIO20 已被编码器占用。录音功能（INMP441 类 I2S 麦克风）以后再规划引脚；
触摸模块已移除（返回功能与编码器长按重合），空出的 **GPIO4** 可优先给麦克风用。

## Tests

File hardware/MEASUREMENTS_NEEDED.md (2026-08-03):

# AgentBell PCB 实物测量单

在画最终封装前填写。尺寸单位统一为 mm，照片尽量垂直拍摄并放一把钢尺或游标卡尺作参照。

## ESP32-C3 SuperMini

- [x] PCB 长：约 22.50 mm（资料文字 22.52 mm）
- [x] PCB 最大宽：18.00 mm
- [ ] PCB 厚：____
- [x] 每侧连接位数：8
- [x] 同一排相邻连接位中心距：2.54 mm
- [x] 两排焊盘基准间距：15.24 mm
- [ ] 孔中心到 PCB 边缘距离：____
- [ ] 孔径：____
- [ ] 边缘是完整孔 / 半孔（圈选）：____
- [ ] 底面最高元件距 PCB 底面的高度：____
- [ ] USB-C 外壳相对 PCB 边缘伸出量：____
- [x] 天线在 USB-C 的另一端
- [x] 正面/尺寸图：资料已提供
- [ ] 手头实物背面高清照片：待提供（用于确认平贴净高和焊接可达性）

## 无源蜂鸣器模块

- [ ] 模块长×宽：____ × ____
- [ ] 3P 接口针距：____
- [ ] 3P 实际线序（从某一明确方向看）：____ / ____ / ____
- [ ] 蜂鸣器本体直径或长×宽：____
- [ ] 蜂鸣器高度：____
- [ ] 蜂鸣器脚距/焊盘间距：____
- [ ] 蜂鸣器本体是否有 `+` 标记：____
- [ ] 模块晶体管丝印：____
- [ ] 模块电阻实测值：____
- [ ] 3.3V 下是否正常发声：____
- [ ] 正反面照片：待提供

## 振动马达模块

- [ ] 模块长×宽：____ × ____
- [ ] 3P 实际线序：____ / ____ / ____
- [ ] 马达外形尺寸：____
- [ ] 额定电压：____
- [ ] 启动峰值电流：____
- [ ] 稳态电流：____
- [ ] 模块驱动管丝印：____
- [ ] 3.3V/5V 下的触发极性：____
- [ ] 正反面照片：待提供

## 触摸模块

- [ ] 模块长×宽：____ × ____
- [ ] 芯片丝印：____
- [ ] 3P 实际线序：____ / ____ / ____
- [ ] 3.3V 时空闲输出电压：____
- [ ] 触摸时输出电压：____
- [ ] 计划覆盖的外壳材料及厚度：____
- [ ] 正反面照片：待提供

## 旋转编码器

- [ ] 模块长×宽：____ × ____
- [ ] 裸编码器型号/丝印：____
- [ ] 轴心到 PCB 安装面的高度：____
- [ ] 轴长度：____
- [ ] 轴直径：____
- [ ] 轴型（圆轴/D 轴/梅花）：____
- [ ] 定位柱位置和直径：____
- [ ] 固定脚/焊脚尺寸：____
- [ ] 每格正交计数：____
- [ ] 正反面和侧面照片：待提供

## OLED

- [ ] 屏模块长×宽：____ × ____
- [ ] 安装孔位置和孔径：____
- [ ] 接口类型/针距：____
- [ ] 从正面左到右线序：____ / ____ / ____ / ____
- [ ] 是否使用可插拔排线：____
- [ ] 主板到屏幕所需线长：____

## 整机

- [ ] 供电：USB 常供 / 锂电 / 两者都要：____
- [ ] 期望 PCB 最大长×宽：____ × ____
- [ ] 安装孔数量、位置、孔径：____
- [ ] 外壳内部可用高度：____
- [ ] 编码器、触摸区、屏幕接口的期望相对位置：____
- [ ] 蜂鸣器声孔位置：____
- [ ] 马达希望贴近的外壳面：____

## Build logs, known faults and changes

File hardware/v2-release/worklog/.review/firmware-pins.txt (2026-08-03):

#define OLED_SDA   5      // I2C 数据
#define OLED_SCL   6      // I2C 时钟
#define OLED_ADDR  0x3C   // 少数屏是 0x3D
#define TOUCH_PIN  4      // 触摸模块 SIG（数字输入）
#define BUZZER_PIN 3      // 蜂鸣器 I/O
#define VIB_PIN    10     // 震动模块 IN
#define ENC_CLK 1     // A 相
#define ENC_DT  7     // B 相
#define ENC_SW  20    // 按压（低有效，用内部上拉）
#define ENC_RAW_PER_DETENT 2   // 本编码器每个物理档位产生的正交沿数（实测 div=4 时每 2 档动一下 → 2/档）
#define VIB_ACTIVE_HIGH     true    // 震动模块触发极性（装上后不对就翻这里）

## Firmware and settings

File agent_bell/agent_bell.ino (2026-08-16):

// ============================================================================
//  AgentBell — ESP32-C3 SuperMini + SSD1306 128x64 OLED 智能体提醒设备
// ----------------------------------------------------------------------------
//  作用：电脑上的 Claude Code / Codex 完成一轮对话时，通过局域网 HTTP 通知本设备，
//        它会「蜂鸣 + 震动」并在 OLED 上显示：哪台电脑、哪个智能体、哪个对话。
//
//  架构：本设备是 HTTP 服务器（局域网内任意电脑都能 push）。电脑侧用 Claude 的
//        Stop hook / Codex 的 notify 程序，在对话结束时 POST /notify 过来。
//
//  录音→语音识别→回填输入框那部分留待以后（GPIO4 已空出，可留给麦克风）。
//
//  编译（Huge App 分区容纳中文字体）：
//    arduino-cli compile --fqbn esp32:esp32:esp32c3:PartitionScheme=huge_app \
//        --output-dir agent_bell/build agent_bell
//  定义 SIM_DEMO 宏则跳过联网、开机自注入示例通知（给 Wokwi 预览界面用）。
// ============================================================================

#include <Arduino.h>
#include <Wire.h>
#include <U8g2lib.h>
#include <time.h>          // 待机屏时钟：SNTP 同步后 time()/localtime() 取本地时间
#include <sys/time.h>      // settimeofday（SIM_DEMO 预览注入假时间用）

#ifndef SIM_DEMO
  #include <WiFi.h>
  #include <WebServer.h>
  #include <ESPmDNS.h>
  #include <DNSServer.h>     // 配网热点的强制门户（captive portal）DNS
  #include <WiFiUdp.h>       // 局域网发现应答（一个广播包换掉 254 次 TCP 扫描）
  #include <Preferences.h>   // 把网页里的开关存进 NVS，掉电不丢
#endif

#ifdef INO_SIM
  #include <sim_inject.h>    // ino-sim 屏幕模拟器：从 scenario 的 var 注入界面数据
#else
  #include <esp_sleep.h>     // 「关机」=深睡眠；转动编码器（GPIO1）唤醒
  #include <driver/gpio.h>   // gpio_hold_en：睡眠期把蜂鸣/震动脚锁在「不响」电平
#endif

// 前置声明：有函数在这两个类型定义之前被 arduino-cli 自动生成原型引用（Note* / ListAnim&），先声明避免"未命名类型"
struct Note;
struct ListAnim;
struct SetMeta;
enum SubMenu { SUB_NONE, SUB_MELODY };                          // 选项子列表（当前仅提示音用竖列表）
enum SetId   { SET_BUZVOL, SET_VIBVOL, SET_FBMODE, SET_FBVOL, SET_FBVIB, SET_ENCSENS, SET_LSTYLE, SET_RSTYLE, SET_AUTOOFF, SET_AUTOPWR };  // 滑块设置项（定义在顶部，供自动原型引用）

// ===== 硬件引脚（ESP32-C3 SuperMini，全部避开 strapping 脚 2/8/9）=====
#define OLED_SDA   5      // I2C 数据
#define OLED_SCL   6      // I2C 时钟
#define OLED_ADDR  0x3C   // 少数屏是 0x3D
#define BUZZER_PIN 3      // 蜂鸣器 I/O
#define VIB_PIN    10     // 震动模块 IN
// 触摸模块已移除（2026-07-30）：其"返回"功能与编码器长按完全重合，PCB 放不下遂砍掉。
// GPIO4 因此空出 —— 麦克风（以后录音用）可优先考虑它（原预留的 7/20 已被编码器占用）。
// —— 旋转编码器 HW-040（⚠ 电源脚 + 接 3V3，绝不能接 5V！输出电平跟随供电，5V 会烧 C3）——
#define ENC_CLK 1     // A 相（兼作「关机」的深睡眠唤醒脚：C3 只有 GPIO0-5 能唤醒，恰好在范围内）
#define ENC_DT  7     // B 相
#define ENC_SW  20    // 按压（低有效，用内部上拉；不在 GPIO0-5 内 → 关机后按它无法开机，得转旋钮）
#define ENC_RAW_PER_DETENT 4   // 本编码器每个物理档位产生的正交沿数（v2 PCB 板载编码器实测 4/档；旧 HW-040 模块是 2/档，换回模块记得改回 2）
// 旋转方向 encReversed、灵敏度 encDetents（每几档动一步）都是运行时设置（菜单/网页可调）

// ===== 模块触发极性 =====
// 蜂鸣器：无源 + 低电平触发（PNP 驱动），发声/静音逻辑在 ToneBuzzer 内处理，无需在此配。
#define VIB_ACTIVE_HIGH     true    // 震动模块触发极性（装上后不对就翻这里）

// ===== 联网配置 =====
// WiFi 凭据来源（优先级）：NVS 存的（配网写入）→ secrets.h（编译期烧录）→ 占位符。
// 到了陌生网络：开机连不上 → 自动开 AgentBell-XXXX 热点 + 配置页；也可菜单「重新配网」手动进。
#if __has_include("secrets.h")
  #include "secrets.h"
#else
  const char* WIFI_SSID = "YOUR_WIFI_SSID";
  const char* WIFI_PASS = "YOUR_WIFI_PASSWORD";
#endif
const char* MDNS_NAME = "agent-bell";      // mDNS 主机名（仅供 /notify 发现，界面不再显示）
char wifiSsid[33] = "";                    // 实际使用的凭据（loadWifiCred 决定来源）
char wifiPass[65] = "";

// ============================================================================
//  声音配置（想换提示音，改这里就够了）
//  蜂鸣器（无源）音序：ToneSeg = {起始频率Hz, 结束频率Hz, 时长ms}
//    · f1==f2 → 稳定音；  f1≠f2 → 从 f1 连贯滑到 f2（滑音）；  f1==0 → 静音间隔
//  震动马达：纯时长数组（开,关,开…，从「开」起，单位 ms）
// ============================================================================
struct ToneSeg { uint16_t f1, f2, ms; };
// —— Agent 完成通知：多种可选提示音（网页可试听/选用）。f1==f2 稳定音；f1≠f2 滑音；f1==0 静音 ——
static const ToneSeg TONE_DINGDONG[] = { {1319,1319,180},{0,0,70},{1047,1047,600} };                              // 叮咚·经典下行
static const ToneSeg TONE_TRIAD[]    = { {1568,1568,150},{0,0,45},{1319,1319,150},{0,0,45},{1047,1047,520} };     // 柔和三音下行
static const ToneSeg TONE_UP[]       = { {1047,1047,140},{0,0,40},{1319,1319,140},{0,0,40},{1568,1568,460} };     // 上行叮铃
static const ToneSeg TONE_DOUBLE[]   = { {1760,1760,90},{0,0,90},{1760,1760,90} };                               // 双叮·短促
static const ToneSeg TONE_ARP[]      = { {784,784,120},{0,0,28},{1047,1047,120},{0,0,28},{1319,1319,120},{0,0,28},{1568,1568,420} }; // 琶音上行
static const ToneSeg TONE_SLIDE[]    = { {1047,1047,110},{1047,784,560},{784,784,320} };                         // 滑音·叮———咚
static const ToneSeg TONE_SINGLE[]   = { {988,988,520} };                                                        // 单长音·简洁
struct Melody { const char* name; const ToneSeg* seq; uint8_t len; };
#define MEL(a) (uint8_t)(sizeof(a) / sizeof((a)[0]))
static const Melody MELODIES[] = {
  {"叮咚·经典", TONE_DINGDONG, MEL(TONE_DINGDONG)},
  {"柔和三音",  TONE_TRIAD,    MEL(TONE_TRIAD)},
  {"上行叮铃",  TONE_UP,       MEL(TONE_UP)},
  {"双叮·短促", TONE_DOUBLE,   MEL(TONE_DOUBLE)},
  {"琶音上行",  TONE_ARP,      MEL(TONE_ARP)},
  {"滑音",      TONE_SLIDE,    MEL(TONE_SLIDE)},
  {"单长音",    TONE_SINGLE,   MEL(TONE_SINGLE)},
};
static const int MEL_N = sizeof(MELODIES) / sizeof(MELODIES[0]);
static const uint16_t ALERT_VIB[]  = { 450, 180, 450 };    // 通知震动：长震-停-长震
// —— 按键 / 反馈音（短促，跟随强度滑条）——
static const ToneSeg TAP_TONES[]   = { {3000, 3000, 45} };  // 旋钮反馈：短促「嘀」
static const ToneSeg FB_TONES[]    = { {2637, 2637, 110} }; // 调强度时的反馈音
static const uint16_t FB_VIB[]     = { 220 };              // 调强度反馈短震
static const uint16_t TAP_VIB[]    = { 95 };               // 旋钮反馈：轻震（够长以启动马达）

// 蜂鸣器是无源的：靠方波频率发声（音高可调）；震动马达用 PWM 占空比调强度。
static const uint32_t VIB_FREQ = 20000;   // 震动马达 PWM 载波，占空比=震动强度

// ===== 显示对象：SSD1306 128x64，硬件 I2C，F=全缓冲（1KB RAM）=====
U8G2_SSD1306_128X64_NONAME_F_HW_I2C u8g2(U8G2_R0, /*reset=*/ U8X8_PIN_NONE);
// 中文用文泉驿 GB2312 全字库（存 flash，故需 huge_app）；大号拉丁字体给智能体名。
#define FONT_CN   u8g2_font_wqy12_t_gb2312
#define FONT_BIG  u8g2_font_helvB14_tr
#define FONT_CLOCK u8g2_font_logisoso20_tn   // 待机屏时钟数字（纯数字字体，含 : 和 -）
#define FONT_CLOCK_XL u8g2_font_logisoso26_tn // 「大字时间」样式用更大号数字
#include "astronaut_frames.h"   // 绕轴自转太空人逐帧位图（tools/gen_astronaut.py 生成）

#ifndef SIM_DEMO
WebServer server(80);
#endif

// ============================================================================
//  非阻塞脉冲器：按节奏数组驱动一个输出脚（蜂鸣器 / 震动），全程不 delay。
// ============================================================================
class Pulser {
 public:
  void begin(uint8_t pin, bool activeHigh, uint32_t freq) {
    pin_ = pin; activeHigh_ = activeHigh;
    pinMode(pin_, OUTPUT);                      // 同蜂鸣器：先锁「不动」电平再挂 LEDC
    digitalWrite(pin_, activeHigh ? LOW : HIGH);
#ifdef INO_SIM
    (void)freq;                                 // 仿真主机端无 LEDC，退化为数字开关
#else
    ledcAttach(pin_, freq, 8);                  // 8-bit PWM，占空比即强度/响度
#endif
    setVolume(100);
    ovDuty_ = duty_;
    on_ = false; active_ = false; drive();      // 上电即置为「不响」
  }
  void setVolume(int v) {                        // 0-100 → 占空比；100=满占空比(直流常通,最响)
    if (v < 0) v = 0; if (v > 100) v = 100;
    duty_ = (uint32_t)v * 256 / 100;             // 100→256：8-bit 的"100%"特值=DC 常通
  }
  void trigger(const uint16_t* pat, uint8_t len, int volOverride = -1) {
    ovDuty_ = (volOverride >= 0) ? (uint32_t)volOverride * 256 / 100 : duty_;   // 可临时指定音量(0-100)
    pat_ = pat; len_ = len; idx_ = 0;
    budget_ = 0;                                  // 保险：整段节奏的总时长（+余量）
    for (uint8_t i = 0; i < len; i++) budget_ += pat[i];
    budget_ += 400;
    on_ = true; active_ = true; tMark_ = tStart_ = millis(); drive();
  }
  void stop() { active_ = false; on_ = false; drive(); }
  bool busy() const { return active_; }
  void update() {
    if (!active_) return;
    // 保险：主循环若被别的任务（如 WiFi 重连）饿到，超时强制静默，绝不长震
    if (millis() - tStart_ > budget_) { stop(); return; }
    if (millis() - tMark_ >= pat_[idx_]) {
      idx_++;
      if (idx_ >= len_) { stop(); return; }      // 节奏走完
      on_ = !on_; tMark_ = millis(); drive();     // 开/关交替
    }
  }
 private:
  void drive() {
#ifdef INO_SIM
    bool lvl = on_ ? activeHigh_ : !activeHigh_;
    digitalWrite(pin_, lvl ? HIGH : LOW);
#else
    uint32_t d = on_ ? ovDuty_ : 0;
    ledcWrite(pin_, activeHigh_ ? d : (256 - d));   // 低有效则反相（满刻度 256）
#endif
  }
  uint8_t pin_ = 0; bool activeHigh_ = true; uint32_t duty_ = 255, ovDuty_ = 255;
  const uint16_t* pat_ = nullptr; uint8_t len_ = 0, idx_ = 0;
  bool on_ = false, active_ = false; unsigned long tMark_ = 0, tStart_ = 0, budget_ = 0;
};

// ============================================================================
//  无源蜂鸣器音调播放器：按 {频率,时长} 音序发方波发声，可调音高/音量，非阻塞。
//  低电平触发（PNP）：占空比 50% 最响、导通在低电平；静音时输出高电平（关断）。
// ============================================================================
class ToneBuzzer {
 public:
  void begin(uint8_t pin) {
    pin_ = pin;
    // 先把脚锁在「静音」电平再挂 LEDC：ledcAttach 的初始占空比是 0（输出低），
    // 而蜂鸣器是 PNP 低有效 —— 会有一瞬直流灌进线圈（约 200mA + 一声「咔」）。
    // 开机本就是电池最紧张的时刻，这个尖峰要掉。
    pinMode(pin_, OUTPUT);
    digitalWrite(pin_, HIGH);
#ifndef INO_SIM
    ledcAttach(pin_, 2700, 8);                 // 先挂上，频率随音序实时改
#endif
    idleSilent();
  }
  void setVolume(int v) { vol_ = v < 0 ? 0 : (v > 100 ? 100 : v); }
  void play(const ToneSeg* seq, uint8_t n, int volOverride = -1) {
    seq_ = seq; n_ = n; i_ = 0; active_ = true; lastFreq_ = -1;
    ovVol_ = (volOverride >= 0) ? volOverride : vol_;
    budget_ = 0;                                 // 保险：整段音序总时长（+余量）
    for (uint8_t k = 0; k < n; k++) budget_ += seq[k].ms;
    budget_ += 400;
    tSeg_ = tStart_ = millis(); applyCur();
  }
  void stop() { active_ = false; idleSilent(); }
  bool busy() const { return active_; }
  void update() {
    if (!active_) return;
    unsigned long now = millis();
    // 保险：主循环被饿到（WiFi 重连抢 CPU 等）时超时强制静音，绝不长鸣
    if (now - tStart_ > budget_) { stop(); return; }
    if (now - tSeg_ >= seq_[i_].ms) {           // 本段结束 → 下一段
      if (++i_ >= n_) { stop(); return; }
      tSeg_ = now; applyCur(); return;
    }
    if (now - tFreq_ >= 8) applyCur();          // 滑音：约每 8ms 刷新一次频率
  }
 private:
  void applyCur() {
    tFreq_ = millis();
#ifndef INO_SIM
    const ToneSeg& s = seq_[i_];
    if (s.f1 == 0) { idleSilent(); lastFreq_ = -1; return; }        // 静音段
    uint32_t el = millis() - tSeg_; if (el > s.ms) el = s.ms;
    int span = s.ms ? (int)s.ms : 1;
    int f = (int)s.f1 + ((int)s.f2 - (int)s.f1) * (int)el / span;   // 线性滑音
    if (f != lastFreq_) { ledcChangeFrequency(pin_, f, 8); lastFreq_ = f; }
    ledcWrite(pin_, 128 + (uint32_t)(100 - ovVol_) * 128 / 100);    // 占空比=音量(50%最响)
#endif
  }
  void idleSilent() {
#ifndef INO_SIM
    ledcWrite(pin_, 256);                       // 高电平=关（无源蜂鸣器直流不发声）
#else
    digitalWrite(pin_, HIGH);
#endif
  }
  uint8_t pin_ = 0; const ToneSeg* seq_ = nullptr; uint8_t n_ = 0, i_ = 0;
  bool active_ = false; int vol_ = 100, ovVol_ = 100, lastFreq_ = -1;
  unsigned long tSeg_ = 0, tFreq_ = 0, tStart_ = 0, budget_ = 0;
};

Pulser vibrator;
ToneBuzzer buzzer;

// ============================================================================
//  旋转编码器 HW-040：正交状态表解码（CLK/DT 双中断累加，不丢步）+ 按键短/长按
// ============================================================================
static const int8_t QTAB[16] = {0,-1,1,0, 1,0,0,-1, -1,0,0,1, 0,1,-1,0};
volatile int32_t encRaw = 0;      // 原始正交计数
volatile uint8_t encPrev = 0;
bool encReversed = false;         // 旋钮方向反转（运行时设置，存 NVS）
int  encDetents  = 1;             // 每几个物理档位移动一步（1/2/3，运行时设置，存 NVS）

#ifndef INO_SIM
void IRAM_ATTR encISR() {
  uint8_t cur = (digitalRead(ENC_DT) << 1) | digitalRead(ENC_CLK);
  encPrev = ((encPrev << 2) | cur) & 0x0F;
  encRaw += QTAB[encPrev];
}
#endif

static void encBegin() {
  pinMode(ENC_CLK, INPUT_PULLUP);
  pinMode(ENC_DT,  INPUT_PULLUP);
  pinMode(ENC_SW,  INPUT_PULLUP);
  encPrev = (digitalRead(ENC_DT) << 1) | digitalRead(ENC_CLK);
#ifndef INO_SIM
  attachInterrupt(digitalPinToInterrupt(ENC_CLK), encISR, CHANGE);
  attachInterrupt(digitalPinToInterrupt(ENC_DT),  encISR, CHANGE);
#endif
}

// 消费自上次以来的档位增量（±每档一步；方向可反）
static int encSteps() {
  static int32_t consumed = 0;
  int d = ENC_RAW_PER_DETENT * (encDetents < 1 ? 1 : encDetents);   // 每步所需正交沿数
  int32_t raw;
  noInterrupts(); raw = encRaw; interrupts();
  int s = 0;
  while (raw - consumed >=  d) { s++; consumed += d; }
  while (raw - consumed <= -d) { s--; consumed -= d; }
  return encReversed ? -s : s;
}

// 编码器按键：0=无 1=短按(松手) 2=长按(按住到时)
static int encButton() {
  static bool down = false, longFired = false;
  static unsigned long t0 = 0, tEdge = 0;
  static int lastRaw = HIGH;
  int raw = digitalRead(ENC_SW);                 // 低有效
  if (raw != lastRaw) { tEdge = millis(); lastRaw = raw; }
  bool stable = millis() - tEdge > 25;
  int ev = 0;
  if (stable && raw == LOW && !down) { down = true; longFired = false; t0 = millis(); }
  else if (stable && raw == HIGH && down) { down = false; if (!longFired) ev = 1; }
  if (down && !longFired && millis() - t0 >= 500) { longFired = true; ev = 2; }
  return ev;
}

// ============================================================================
//  通知环形缓冲：暂存「还没看的」通知，最多 8 条（满了新的顶掉最旧的）。
//  不是历史存档 —— 在通知屏按一下旋钮就整批清空（看完即销毁）。
// ============================================================================
struct Note {
  char computer[24];
  char agent[16];
  char conversation[48];
  char message[80];
  unsigned long recv;   // millis() 收到时刻
};

static const int RING_N = 8;
Note ring[RING_N];
int  ringCount = 0;     // 已存条数（≤8）
int  ringHead  = 0;     // 下一个写入位置
int  unread    = 0;     // 未读徽标
int  viewOffset = 0;    // 0=最新，1=次新…；-1=待机（无查看）

// 取「第 k 新」的通知（k=0 最新）。越界返回 nullptr。
Note* noteByOffset(int k) {
  if (k < 0 || k >= ringCount) return nullptr;
  int idx = (ringHead - 1 - k + RING_N) % RING_N;
  return &ring[idx];
}

void addNote(const Note& n) {
  ring[ringHead] = n;
  ringHead = (ringHead + 1) % RING_N;
  if (ringCount < RING_N) ringCount++;
  viewOffset = 0;                          // 跳到最新
  if (unread < ringCount) unread++;
}

bool needRender = true;
unsigned long lastRender = 0;

// ============================================================================
//  运行时可调设置（网页控制台改，存 NVS 掉电不丢）
// ============================================================================
bool buzzerEnabled = true;    // 蜂鸣器总开关
bool vibEnabled    = true;    // 震动总开关
bool dnd           = false;   // 勿扰：收到通知只屏显，不响不震
int  buzzerVol     = 100;     // 通知蜂鸣强度 0-100
int  vibVol        = 100;     // 通知震动强度 0-100
int  alertTone     = 0;       // 选用的提示音索引（对应 MELODIES）
int  feedbackMode  = 0;       // 操作反馈：0=声+震 1=仅震 2=仅声 3=无
int  fbVol         = 60;      // 操作反馈·音量（与通知分开；够明显但比通知小）
int  fbVibVol      = 75;      // 操作反馈·震动强度（与通知分开；需高于马达启动阈值）
int  leftStyle     = 0;       // 待机屏左半模块索引（对应 PANE_NAMES）
int  rightStyle    = 1;       // 待机屏右半模块索引
// —— 省电：闲置多久自动熄屏 / 自动关机（0=不启用）。计时基准见 lastActivity() ——
int  autoOffMin    = 0;       // 无通知且无操作 N 分钟后熄屏（0=关闭）
int  autoPwrMin    = 0;       // 无通知且无操作 N 分钟后关机（0=关闭）
// —— 电源：只有一档「省电但够用」，没有模式选择 ——
// 板上没有 USB 检测脚也没有电池 ADC，固件无法自知供电来源，所以一律按电池的约束跑：
//   · CPU 80MHz + WiFi 调制解调器休眠：省下的连续电流（~60mA）是续航的大头
//   · 发射功率按信号强度自适应，但弱信号时不吝啬——重传比多发几个 dBm 更费电，
//     也更容易撞穿电脑侧的请求超时（实测弱信号下的重传会把延迟拖到 2 秒以上）
//   · 通知响铃/震动封顶：蜂鸣 ~200mA + 马达 ~100mA 会和 WiFi 收包峰值叠在一起，
//     正好是刚收到通知那一刻，小电池带不动就会当场掉电重启
static const int AUTOOFF_MIN_OPTS[] = {0, 1, 2, 5, 10, 20, 30};        // 熄屏可选分钟
static const int AUTOPWR_MIN_OPTS[] = {0, 10, 20, 30, 60, 120, 240};   // 关机可选分钟
static const char* AUTOOFF_OPTS[] = {"关闭", "1 分钟", "2 分钟", "5 分钟", "10 分钟", "20 分钟", "30 分钟"};
static const char* AUTOPWR_OPTS[] = {"关闭", "10 分钟", "20 分钟", "30 分钟", "1 小时", "2 小时", "4 小时"};
static const int AUTO_OPT_N = 7;
// 分钟值 → 选项下标（存的是分钟数，菜单/网页按下标选）
static int autoIdx(const int* tbl, int minutes) {
  for (int i = 0; i < AUTO_OPT_N; i++) if (tbl[i] == minutes) return i;
  return 0;
}
// ===== 待机屏半屏模块池（左右两半都是 64×64，同一池子里任选，菜单/API/桥接共用）=====
// 模块渲染函数在下方"待机屏模块"一节定义；这里先声明，供函数指针表引用。
static void paneAstro(int x0);     static void paneClock(int x0);
static void paneAnalog(int x0);    static void paneBigTime(int x0);
static void paneCalendar(int x0);  static void paneInfo(int x0);
static void paneRadar(int x0);     static void paneMeteor(int x0);
static void paneFlip(int x0);      static void paneHeat(int x0);
static void paneToday(int x0);     static void paneSignal(int x0);
static void panePower(int x0);     static void paneMoon(int x0);
static const char* PANE_NAMES[] = {"宇航员", "数字时钟", "模拟表盘", "竖排大钟", "日历", "信息面板", "雷达扫描", "流星夜空",
                                   "翻页钟", "今日热力", "今日计数", "信号折线", "电源面板", "月相"};
static void (* const PANE_FNS[])(int) = {paneAstro, paneClock, paneAnalog, paneBigTime, paneCalendar, paneInfo, paneRadar, paneMeteor,
                                         paneFlip, paneHeat, paneToday, paneSignal, panePower, paneMoon};
static const int PANE_N = sizeof(PANE_NAMES) / sizeof(PANE_NAMES[0]);

// ===== 统计数据（给「今日热力 / 今日计数」控件）=====
// 存 RTC 内存：复位、深睡「关机」、掉电重启都不丢（真断电才清）。另外每 30 分钟
// 落一次 NVS，断电最多损失半小时的计数；昨日总数在跨日时写入。
#ifndef RTC_DATA_ATTR
  #define RTC_DATA_ATTR
#endif
RTC_DATA_ATTR uint16_t statHour[24] = {0};   // 今天每小时的通知数
RTC_DATA_ATTR uint16_t statToday = 0;        // 今天总数
RTC_DATA_ATTR uint16_t statYesterday = 0;    // 昨天总数（用于对比箭头）
RTC_DATA_ATTR int16_t  statYday = -1;        // 记录归属的 tm_yday，用于跨日翻页
bool statDirty = false;                      // 有未落盘的变动

// ===== 信号折线历史 =====
static const int RSSI_N = 60;                // 最近 60 个采样点（1s 一个 = 1 分钟）
int8_t rssiHist[RSSI_N];
int    rssiCount = 0;                        // 已填充数量（<RSSI_N 时左侧留空）
int    curTxDbm = 0;                         // 当前发射功率（电源面板显示，applyPowerProfile 里更新）
bool screenOff   = false;         // 屏幕是否熄灭（运行时，不持久）
bool notifyWakes = true;          // 熄屏时来通知是否自动亮屏
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
void loop() {
#ifdef INO_SIM
  simRefresh();                 // ino-sim：每帧同步 scenario 注入的界面状态
#endif
#if defined(DIAG_HEARTBEAT) && !defined(SIM_DEMO)
  // 诊断版（-DDIAG_HEARTBEAT）：周期回报状态。USB-CDC 会丢掉主机开口前的早期日志，
  // 靠心跳才能看清设备到底在哪个模式、连的是哪个 SSID。
  {
    static unsigned long lastBeat = 0;
    if (millis() - lastBeat > 2000) {
      lastBeat = millis();
      Serial.printf("[beat] ap=%d wifiStatus=%d ip=%s ssid=\"%s\" wasUp=%d srv=%d up=%lus\n",
                    apMode ? 1 : 0, (int)WiFi.status(),
                    WiFi.localIP().toString().c_str(), wifiSsid,
                    wifiWasUp ? 1 : 0, serverUp ? 1 : 0, millis() / 1000);
    }
  }
#endif
#ifndef SIM_DEMO
  if (apMode) {                 // —— 配网模式：只跑门户 + 屏显，不跑正常 UI ——
    dnsServer.processNextRequest();
    server.handleClient();
    static unsigned long lastApDraw = 0;
    if (millis() - lastApDraw > 500) { lastApDraw = millis(); renderApScreen(); }
    if (millis() - apStartedAt > 10 * 60 * 1000UL) ESP.restart();   // 10min 没人配 → 重启再试原 WiFi
    delay(2);
    return;
  }
  // 只在连上时收 HTTP：掉线时 WebServer 遇半开连接会死等 5s（HTTP_MAX_DATA_WAIT），
  // 用状态守卫跳过即可 —— 不去 stop()/begin() 动 socket（网络已 down 时释放 lwIP
  // 套接字会崩，2026-08-05 实测过）。
  if (WiFi.status() == WL_CONNECTED) { server.handleClient(); httpStuckWatchdog(); }
  discoveryTick();                           // UDP 广播发现应答（不经 WebServer）
  wifiTick();                                // 掉线自愈（安静重试，不抢 CPU）
  // 首次连上 WiFi 后挂载 mDNS（开机没连上时每 2s 补查一次；掉线重连无需重挂）
  static bool mdnsUp = false;
  static unsigned long lastNetChk = 0;
  if (!mdnsUp && millis() - lastNetChk > 2000) {
    lastNetChk = millis();
    if (WiFi.status() == WL_CONNECTED) {
      if (MDNS.begin(MDNS_NAME)) MDNS.addService("http", "tcp", 80);
      mdnsUp = true;
    }
  }
  // 信号折线控件的数据源：每秒采一个 RSSI 样本（滚动窗口，最近 1 分钟）
  {
    static unsigned long lastRssi = 0;
    if (millis() - lastRssi > 1000) {
      lastRssi = millis();
      int8_t v = (WiFi.status() == WL_CONNECTED) ? (int8_t)WiFi.RSSI() : 0;   // 0=离线/无效
      if (rssiCount < RSSI_N) rssiHist[rssiCount++] = v;
      else { memmove(rssiHist, rssiHist + 1, RSSI_N - 1); rssiHist[RSSI_N - 1] = v; }
    }
  }
  // 统计：跨日翻页（哪怕当天一条通知都没有）+ 每 30 分钟落盘
  {
    static unsigned long lastStat = 0;
    if (millis() - lastStat > 60000UL) {
      lastStat = millis();
      struct tm t;
      if (clockNow(t)) statRollIfNeeded(t);
    }
    static unsigned long lastStatSave = 0;
    if (millis() - lastStatSave > 30UL * 60000UL) {
      lastStatSave = millis();
      saveStats();
    }
  }
  // 省电模式下每 60s 按当前信号强度重新定发射功率（换了位置/信号变化就跟着调）
  {
    static unsigned long lastPwrChk = 0;
    if (WiFi.status() == WL_CONNECTED && millis() - lastPwrChk > 60000) {
      lastPwrChk = millis();
      applyPowerProfile();
    }
  }
#endif
  buzzer.update();
  vibrator.update();
  handleInput();

  // 提示音子菜单：停留 ~300ms 自动试听（按通知音量，所听即所得）
  if (uiState == UI_MENU && curSub == SUB_MELODY && subSel != melPreviewed && millis() - melSettleAt > 300) {
    melPreviewed = subSel;
    buzzer.play(MELODIES[subSel].seq, MELODIES[subSel].len);
  }
  // 菜单/调节/弹窗闲置 15s 回待机（滑块页超时退出也把已改的值存盘）
  if (uiState != UI_IDLE && uiState != UI_NOTE && millis() - lastInput > 15000) {
#ifndef SIM_DEMO
    if (uiState == UI_SLIDER) saveSettings();
#endif
    uiState = UI_IDLE;
  }

  // —— 省电：无通知且无操作达到设定时长 → 自动熄屏 / 自动关机（0=关闭）——
  // 计时基准 lastActivity() = 通知与旋钮操作取较晚者，所以正在操作时不会突然黑屏/关机。
  if (autoOffMin > 0 && !screenOff && uiState == UI_IDLE &&
      millis() - lastActivity() > (unsigned long)autoOffMin * 60000UL) {
    Serial.printf("[power] 闲置 %d 分钟，自动熄屏\n", autoOffMin);
    setScreen(false);
  }
  if (autoPwrMin > 0 && millis() - lastActivity() > (unsigned long)autoPwrMin * 60000UL) {
    Serial.printf("[power] 闲置 %d 分钟，自动关机\n", autoPwrMin);
    powerOff();                      // 真机不返回（深睡，转旋钮开机）
    lastInput = millis();            // 仿真端会返回：重置计时，避免每轮重复触发
  }

  // 菜单动画期高刷（~45fps）；待机/通知 40ms（宇航员 80ms/帧，采样需更密才不跳帧；熄屏时 render 直接返回）
  unsigned long interval = (uiState == UI_MENU || uiState == UI_SLIDER || uiState == UI_POPUP ||
                            uiState == UI_WIFI) ? 22 : 40;
  if (needRender || millis() - lastRender > interval) {
    render();
    needRender = false;
    lastRender = millis();
  }
}

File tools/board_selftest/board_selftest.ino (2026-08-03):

// ============================================================================
//  board_selftest.ino — AgentBell v2 载板首次上电自检（不联网、执行器手动触发）
// ----------------------------------------------------------------------------
//  给新焊的板子做最小损失验证：上电先把蜂鸣/震动锁在「不响」电平，然后按顺序
//  自检 I2C → OLED → 编码器；蜂鸣和震动只在你按键时给一个短脉冲（焊错也只响一下）。
//
//  操作：
//    转动旋钮      → 屏幕/串口上计数变化（验证 CLK/DT 相序与方向）
//    短按旋钮      → 蜂鸣 120ms 中等音量（验证 PNP 低有效驱动）
//    长按旋钮 0.5s → 震动 150ms 60% 占空比（验证 NMOS 高有效驱动）
//
//  一切反馈同时走 OLED 和串口 115200：屏幕不亮也能从串口判断卡在哪一步。
//
//  编译烧录（ASCII 字体，无需 huge_app）：
//    arduino-cli compile --fqbn esp32:esp32:esp32c3 --output-dir tools/board_selftest/build tools/board_selftest
//    arduino-cli upload -p COM6 --fqbn esp32:esp32:esp32c3 --input-dir tools/board_selftest/build
// ============================================================================
#include <Arduino.h>
#include <Wire.h>
#include <U8g2lib.h>

// —— 引脚（与正式固件 agent_bell.ino 一致，对应 v2 golden-netlist）——
#define OLED_SDA   5
#define OLED_SCL   6
#define BUZZER_PIN 3     // PNP 低有效：HIGH=静音
#define VIB_PIN    10    // NMOS 高有效：LOW=停
#define ENC_CLK    1
#define ENC_DT     7
#define ENC_SW     20
#define TOUCH_PIN  4     // 预留 TOUCH_SIG，只读不驱动

U8G2_SSD1306_128X64_NONAME_F_HW_I2C u8g2(U8G2_R0, U8X8_PIN_NONE);

// —— 编码器：正交表解码（与正式固件同款）——
static const int8_t QTAB[16] = {0,-1,1,0, 1,0,0,-1, -1,0,0,1, 0,1,-1,0};
volatile int32_t encRaw = 0;
volatile uint8_t encPrev = 0;
void IRAM_ATTR encISR() {
  uint8_t cur = (digitalRead(ENC_DT) << 1) | digitalRead(ENC_CLK);
  encPrev = ((encPrev << 2) | cur) & 0x0F;
  encRaw += QTAB[encPrev];
}

uint8_t i2cAddrs[8]; int i2cN = 0;   // I2C 扫描结果
bool oledOk = false;
int beeps = 0, vibs = 0;             // 已触发次数（上屏）

static void beep120() {              // 短蜂鸣：2700Hz，中低音量（低有效：256=静音,128=最响）
  ledcChangeFrequency(BUZZER_PIN, 2700, 8);
  ledcWrite(BUZZER_PIN, 200);
  delay(120);
  ledcWrite(BUZZER_PIN, 256);
  beeps++;
  Serial.printf("[test] beep #%d done\n", beeps);
}

static void vib150() {               // 短震动：20kHz 载波 60% 占空比
  ledcWrite(VIB_PIN, 153);
  delay(150);
  ledcWrite(VIB_PIN, 0);
  vibs++;
  Serial.printf("[test] vib #%d done\n", vibs);
}

void setup() {
  // ---- 第 0 步：安全默认 —— 执行器先锁死在「不响」电平，再做其它任何事 ----
  pinMode(BUZZER_PIN, OUTPUT); digitalWrite(BUZZER_PIN, HIGH);
  pinMode(VIB_PIN, OUTPUT);    digitalWrite(VIB_PIN, LOW);

  Serial.begin(115200);
  delay(600);                        // 等 USB-CDC 枚举，头几行日志别丢
  Serial.println("\n===== AgentBell v2 board self-test =====");

  // ---- 第 1 步：I2C 总线扫描（OLED 应答 0x3C 或 0x3D）----
  Wire.begin(OLED_SDA, OLED_SCL);
  for (uint8_t a = 8; a < 120 && i2cN < 8; a++) {
    Wire.beginTransmission(a);
    if (Wire.endTransmission() == 0) i2cAddrs[i2cN++] = a;
  }
  Serial.printf("[i2c] %d device(s):", i2cN);
  for (int i = 0; i < i2cN; i++) Serial.printf(" 0x%02X", i2cAddrs[i]);
  Serial.println(i2cN ? "" : " none! check SDA=5 SCL=6 wiring/pullups");

  // ---- 第 2 步：OLED 初始化 + 全亮一闪（看有没有坏点/花屏）----
  bool has3C = false, has3D = false;
  for (int i = 0; i < i2cN; i++) { if (i2cAddrs[i] == 0x3C) has3C = true; if (i2cAddrs[i] == 0x3D) has3D = true; }
  if (has3C || has3D) {
    u8g2.setI2CAddress((has3C ? 0x3C : 0x3D) << 1);
    u8g2.begin();
    u8g2.setBusClock(700000);        // 与正式固件一致；100kHz 全帧要 ~110ms，会把按键采样拖出可感延迟
    oledOk = true;
    u8g2.clearBuffer(); u8g2.drawBox(0, 0, 128, 64); u8g2.sendBuffer();  // 全亮
    delay(400);
    Serial.println("[oled] init OK (full-white flashed)");
  } else {
    Serial.println("[oled] NOT FOUND - continuing with serial only");
  }

  // ---- 第 3 步：编码器（板载上拉已有，内部再并一份无妨）----
  pinMode(ENC_CLK, INPUT_PULLUP);
  pinMode(ENC_DT,  INPUT_PULLUP);
  pinMode(ENC_SW,  INPUT_PULLUP);
  pinMode(TOUCH_PIN, INPUT);         // 预留脚只观察
  encPrev = (digitalRead(ENC_DT) << 1) | digitalRead(ENC_CLK);
  attachInterrupt(digitalPinToInterrupt(ENC_CLK), encISR, CHANGE);
  attachInterrupt(digitalPinToInterrupt(ENC_DT),  encISR, CHANGE);
  Serial.printf("[enc] idle levels CLK=%d DT=%d SW=%d (all should be 1)\n",
                digitalRead(ENC_CLK), digitalRead(ENC_DT), digitalRead(ENC_SW));

  // ---- 执行器挂上 LEDC（初值仍为静默）----
  ledcAttach(BUZZER_PIN, 2700, 8);  ledcWrite(BUZZER_PIN, 256);
  ledcAttach(VIB_PIN, 20000, 8);    ledcWrite(VIB_PIN, 0);

  Serial.println("[ready] rotate=count  short-press=beep  hold-0.5s=vib");
}

void loop() {
  // —— 按键：短按=蜂鸣，长按=震动（与正式固件同样的消抖思路）——
  static bool down = false, longFired = false;
  static unsigned long t0 = 0, tEdge = 0;
  static int lastRaw = HIGH;
  int raw = digitalRead(ENC_SW);
  if (raw != lastRaw) { tEdge = millis(); lastRaw = raw; }
  if (millis() - tEdge > 25) {
    if (raw == LOW && !down) { down = true; longFired = false; t0 = millis(); }
    else if (raw == HIGH && down) { down = false; if (!longFired) beep120(); }
    if (down && !longFired && millis() - t0 >= 500) { longFired = true; vib150(); }
  }

  // —— 状态上屏 + 串口心跳（USB-CDC 复位后重枚举，启动日志常抓不到 → 周期重播关键状态）——
  static int32_t lastShown = INT32_MIN;
  static unsigned long lastBeat = 0;
  int32_t rawCnt; noInterrupts(); rawCnt = encRaw; interrupts();
  if (rawCnt != lastShown && lastShown != INT32_MIN)
    Serial.printf("[enc] raw=%ld (detent=%ld)\n", (long)rawCnt, (long)(rawCnt / 4));
  lastShown = rawCnt;
  if (millis() - lastBeat > 2000) {
    lastBeat = millis();
    Serial.printf("[beat] up=%lus i2c=%d@0x%02X oled=%d enc=%ld sw=%d tp=%d beeps=%d vibs=%d\n",
                  millis() / 1000, i2cN, i2cN ? i2cAddrs[0] : 0, oledOk ? 1 : 0,
                  (long)(rawCnt / 4), digitalRead(ENC_SW), digitalRead(TOUCH_PIN), beeps, vibs);
  }

  // —— 屏幕节流重画（80ms 一帧足够；输入采样不被渲染拖慢）——
  static unsigned long lastDraw = 0;
  if (oledOk && millis() - lastDraw > 80) {
    lastDraw = millis();
    char l[32];
    u8g2.clearBuffer();
    u8g2.setFont(u8g2_font_6x12_tr);
    u8g2.drawStr(0, 10, "AgentBell v2 selftest");
    snprintf(l, sizeof(l), "I2C:%d dev @0x%02X", i2cN, i2cN ? i2cAddrs[0] : 0);
    u8g2.drawStr(0, 24, l);
    snprintf(l, sizeof(l), "ENC:%-6ld SW:%s", (long)(rawCnt / 4), digitalRead(ENC_SW) ? "up" : "DOWN");
    u8g2.drawStr(0, 38, l);
    snprintf(l, sizeof(l), "beep:%d vib:%d tp:%d", beeps, vibs, digitalRead(TOUCH_PIN));
    u8g2.drawStr(0, 52, l);
    u8g2.drawStr(0, 63, "press=beep hold=vib");
    u8g2.sendBuffer();
  }
  delay(1);
}

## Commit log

2026-07-15 AgentBell 智能体门铃：ESP32-C3 固件 + 电脑侧通知器 + 旋转编码器丝滑菜单 UI
    - 固件 agent_bell/：SSD1306 OLED 中文界面、无源蜂鸣器音调提示音库、震动、触摸键、HW-040 旋转编码器丝滑菜单（缓动/滑块/自转宇航员待机）
    - 电脑侧 tools/agent-bell/：Claude Stop hook / Codex notify → 局域网 HTTP 通知设备
    - tools/ino-sim/：屏幕模拟器；tools/gen_astronaut.py：宇航员帧生成
    - WiFi 凭据经 secrets.h（gitignore）隔离，仓库不含真实凭据
2026-07-16 hardware/：单板 PCB 设计源（锂电充电电源架构 + 原理图连接表 + 带LCSC编号BOM）
    - 紧凑手掌方块，嘉立创贴片：蜂鸣/编码器/马达/触摸IC/电源全 SMD
    - 主控 SuperMini 用 2×8 母座手焊插装；OLED 排线外接；触摸做成 PCB 铜箔片
    - 供电：USB-C→TP4056→锂电→电源开关→3.3V LDO→3V3 轨
    - 驱动极性对齐现固件（蜂鸣 PNP 低有效 / 马达 NPN 高有效 + 续流二极管）
    [BOM.csv]
2026-08-03 桥接程序 2.0：pywebview TE 面板 UI + macOS 支持 + 双平台安装包 CI
    - ui/index.html 单文件前端（TE 铝面板语言，浏览器可 mock 预览）
    - watcher_mac.py：macOS 通知中心 SQLite 轮询（接口与 WinRT 版一致）
    - 自启/权限/托盘全平台分支；配置路径 mac 用 Application Support
    - pack/: Inno Setup(win) + PyInstaller .app + hdiutil DMG(mac)
    - .github/workflows/build-installers.yml：云端出 Setup.exe + 双架构 DMG
2026-08-03 CI 修复：中文语言包随仓库带；去掉已退役的 macos-13 Intel 跑道
2026-08-03 固件大版本：AP 配网 + 网页控制台 + 关机深睡 + 菜单重组 + 通知屏重设计；v2 PCB 定板
    固件（agent_bell.ino，v2 板已验证）：
    - 配网：凭据存 NVS，连不上自动开 AgentBell-XXXX 热点+强制门户；菜单可「重新配网」
    - 网页设置控制台（PROGMEM 单页）：全部设置读写/试听试震/最近通知，TE 铝面板风格
    - 关机=深度睡眠（gpio_hold 锁执行器静默电平），转动编码器唤醒
    - 菜单按「勿扰→通知→反馈→待机屏→旋钮→电源→系统」重组；勿扰/旋钮方向短按即切
    - 通知屏重设计：顶栏文字垂直居中+中文回退、图标行、像素级省略号截断、k/N 位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
    [AgentBell-BOM.csv, AgentBell-BOM.xlsx, BOM.csv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]
2026-08-04 修复 WiFi 掉线导致整机卡死 + 蜂鸣器间歇乱响；新增自动熄屏/自动关机
    问题：WiFi 断开后屏幕定格、旋钮失灵、蜂鸣器间歇长鸣。
    根因两层（真机实测确认）：
    - C3 是单核，内核 autoReconnect 的「失败即刻重试」紧循环优先级高于 Arduino
    主循环，把 loop 饿到 buzzer.update()/handleInput() 跑不到 → 音序卡在发声段
    变成间歇长鸣、旋钮无响应；
    - 第一版修复用 server.stop() 躲 HTTP_MAX_DATA_WAIT 的 5s 死等，但网络接口已
    down 时释放 lwIP 套接字会崩 → 崩溃重启循环（OLED 有独立显存，芯片挂了就永远
    停在最后一帧，表现为「屏幕卡死」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
    [agent_bell.ino]
2026-08-13 电池供电掉电重启：诊断 + 三档电源模式；通知看完即销毁
    ## 掉电（欠压）重启
    现象：电池供电时卡在"WiFi 连接失败"、屏幕定格、蜂鸣器连续响。
    定位：v2 电池路径 VBAT→SS34→SuperMini 板载 LDO→3.3V 余量只有零点几伏
    （3.7V 电池 − 0.15V 内阻 − 0.40V 二极管 ≈ 3.15V，LDO 需 ≈3.6V），WiFi 发射
    峰值电流一来就欠压复位；OLED 有独立显存，芯片挂了停在最后一帧像"卡死"。
    真机 /api/info 已抓到 brownouts=1 实证。
    - esp_reset_reason() 判掉电，计数存 RTC 内存 + NVS 粘性标记（断电不忘）
    - 掉电后先显示「电池电压不足·请充电」并等 2.5s（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
    [agent_bell.ino]
2026-08-16 macOS 只驻留菜单栏：不进 Dock（LSUIElement + 运行时活动策略）
    pywebview 的 cocoa 后端在导入时把 NSApp 活动策略设成 Regular，光有
    Info.plist 的 LSUIElement 会被它覆盖，所以两处都要：
    · .app 加 LSUIElement=true（启动那一刻就没有 Dock 图标）
    · 预热 cocoa 后端后立刻设回 Accessory（消掉 Dock 图标闪烁）
    菜单栏图标挂载失败则恢复 Regular + 亮出窗口兜底，避免用户没有入口。
    顺带：darwin_nsapplication 改到 Icon 构造参数（原先传给 run_detached
    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
2026-08-16 文档：说明 macOS 只驻留菜单栏（不进 Dock）及其实现约束
2026-08-16 修连接经常失败：三个实测确认的根因 + 支持多台电脑同连一台设备
    诊断用真机压测做的，每条都有数字。
    固件（agent_bell.ino）：
    · lastActivity() 纳入 HTTP 活动（新增 lastNetAt + 各 handler netTouch()）。
    这是「经常连不上」的主因：自动关机 120 分钟只看「有没有通知/有没有转旋钮」，
    电脑每 20 秒探活完全不算活动 → 安静两小时后设备深睡离网，只能手动转旋钮唤回。
    实证：把自动关机设成 10 分钟 + 持续轮询，13 分钟 0 失败、uptime 单调递增。
    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
2026-08-16 发现改用 UDP 广播：一个包换掉 254 次 TCP 扫描（扫描会自伤设备）
    第四路排查的实测结论推翻了原先的判断，据此补两处：
    1. 子网扫描假阴性的真凶不是「无关网段抢占并发预算」（本机只列出一个 /24，
    254/64×1.0s = 恰好 4 秒，是跑完整整四波确实没命中），而是**扫描风暴自伤设备**：
    按 1.0s 超时折算的漏检率 —— 空闲 5% / 风暴中 20% / 风暴停止 2 秒后仍 33%。
    扫描器把它要找的设备打趴了，然后报告「没找到」。日志里「扫描未找到」紧接着
    「缓存地址可用」这个自相矛盾的顺序就是这个自伤的指纹。
    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
2026-08-16 新图标 + 修 macOS 菜单栏图标不显示
    图标：从项目自己的设计语言里长出来，不再用通用金铃铛。
    · 应用图标 = 一小块 AgentBell 面板：拉丝铝 squircle + 内凹深色屏 + 屏里印 TE 橙铃铛。
    深浅对比让它在 32px 也立得住；16~24px 改用只留橙铃铛的简化版（那种尺寸机身会糊）。
    · 画法收拢到 pack/icon_art.py 一处定义，应用图标 / Windows 托盘 / macOS 菜单栏
    共用同一套铃铛几何，看起来是一家人。两个 spec 的 datas 都带上它。
    菜单栏图标不显示（用户报告：位置能点、能弹菜单，但看不到图标）的根因：
    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
2026-08-16 修 macOS 收不到真实通知：通知库路径在新系统上早就搬走了
    用户报告：Mac 上点「发送测试通知」能响（那条不经过通知库），但 Claude 真正跑完
    却永远不转发。三处根因，都在 macOS 这一端：
    1. **库路径过时（主因）**。watcher_mac 只认
    `$(getconf DARWIN_USER_DIR)com.apple.notificationcenter/db2/db` ——
    那是 macOS 11 及更早的位置；12 (Monterey) 起 usernoted 搬进了
    `~/Library/Group Containers/group.com.apple.usernoted/db2/db`。
    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
